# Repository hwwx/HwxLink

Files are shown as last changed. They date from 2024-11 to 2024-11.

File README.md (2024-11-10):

# HwxLink
This design aims to realize a miniaturized integrated multifunctional intelligent terminal, so it is proposed that the design is capable of accomplishing the following functions:
-	High-precision attitude sensing capability
-	Intelligent device control terminal
-	Wireless external sensor
-	Intelligent temperature detection
-	Portable DDS system
-	Simple Oscilloscope

# Repository Structure
```plaintext
HwxLink/
│
├── README.md
├── LICENSE
├── hardware/              # Hardware-related design
│   ├── pcb_layout/        # PCB design files
│   └── 3d_models/         # 3D models (if there are case designs, etc.)
│
├── software/              # Software-related code
│   ├── HwxLink_Version_3/ # Firmware code (embedded development)
│
├── words/                 # Reports and documentation
│   ├── design_report/     # Design report
│   ├── presentation/      # Design presentation
│   └── datasheets/        # Datasheets (chip or module-related documents)
│
└── images/                # Images and diagrams
    └── diagrams/          # Design diagrams, schematics.
```
# Design details
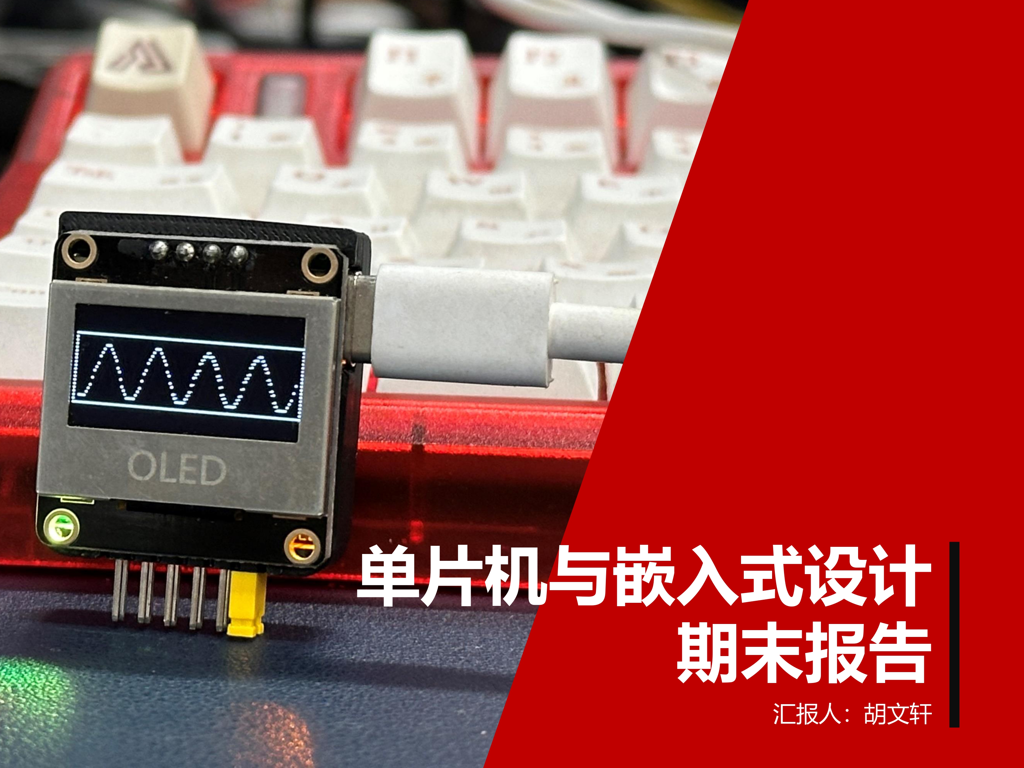
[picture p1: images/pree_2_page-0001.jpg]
Page 1

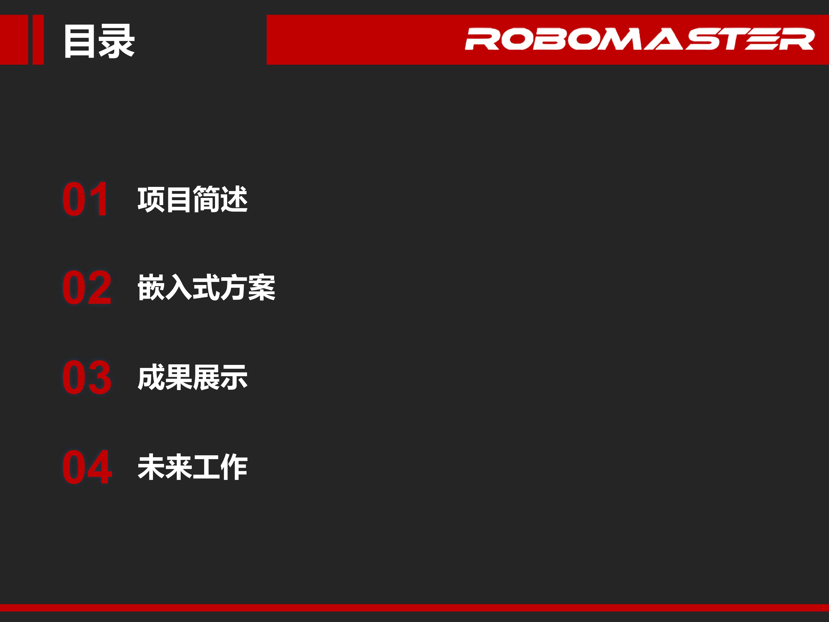
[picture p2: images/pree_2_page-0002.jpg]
Page 2

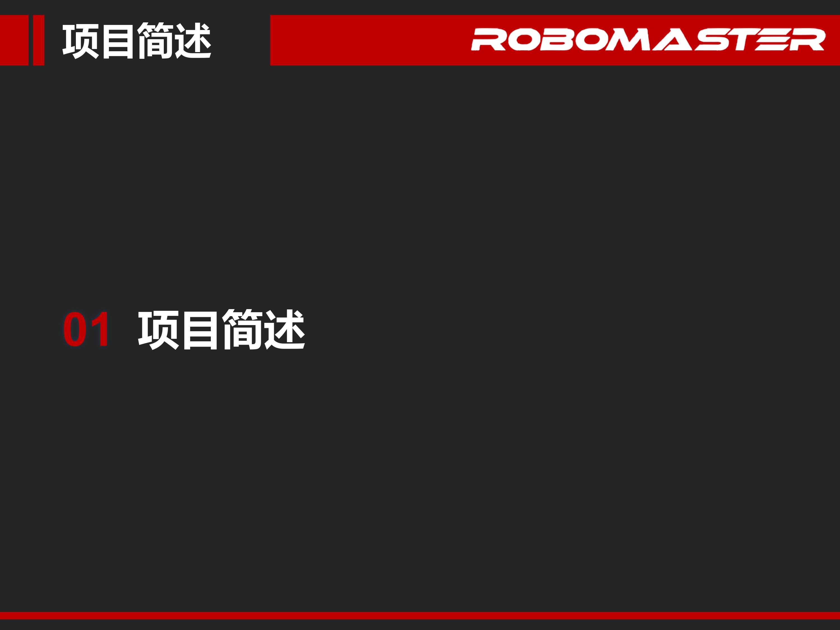
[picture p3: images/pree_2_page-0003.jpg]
Page 3

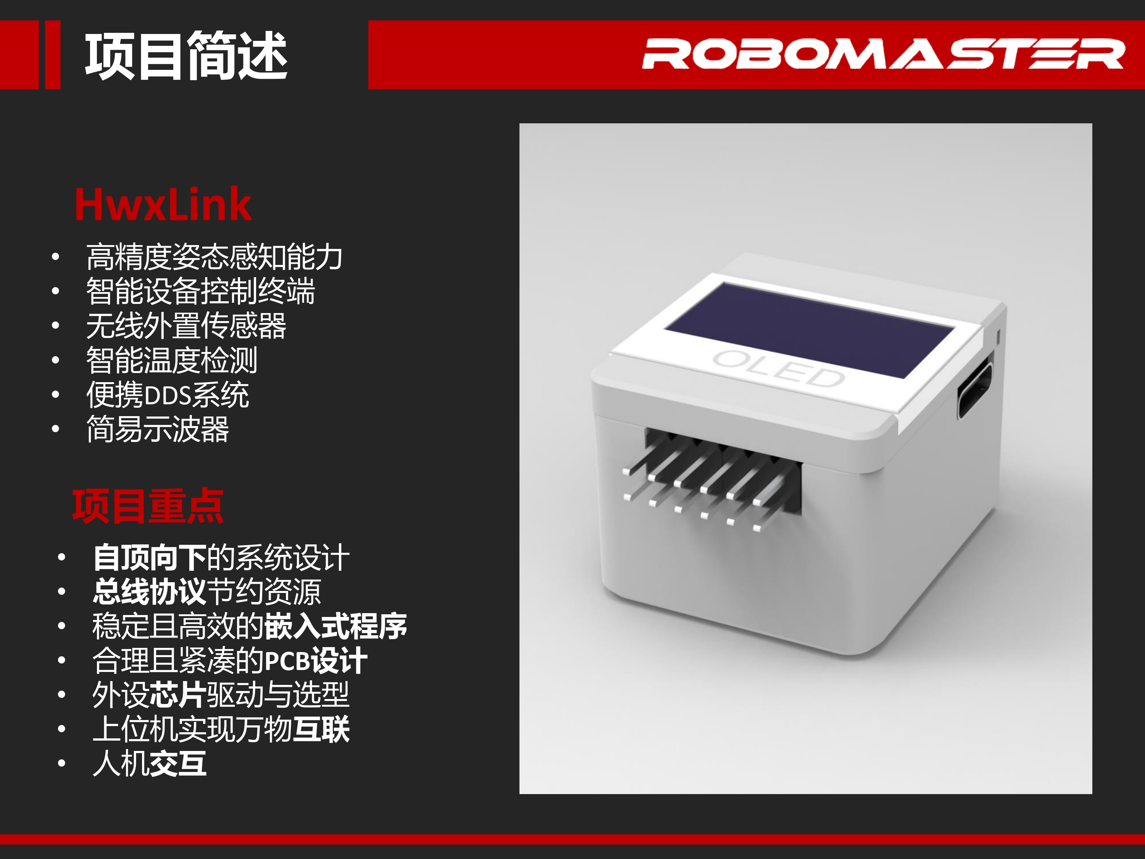
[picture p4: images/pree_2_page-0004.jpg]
Page 4

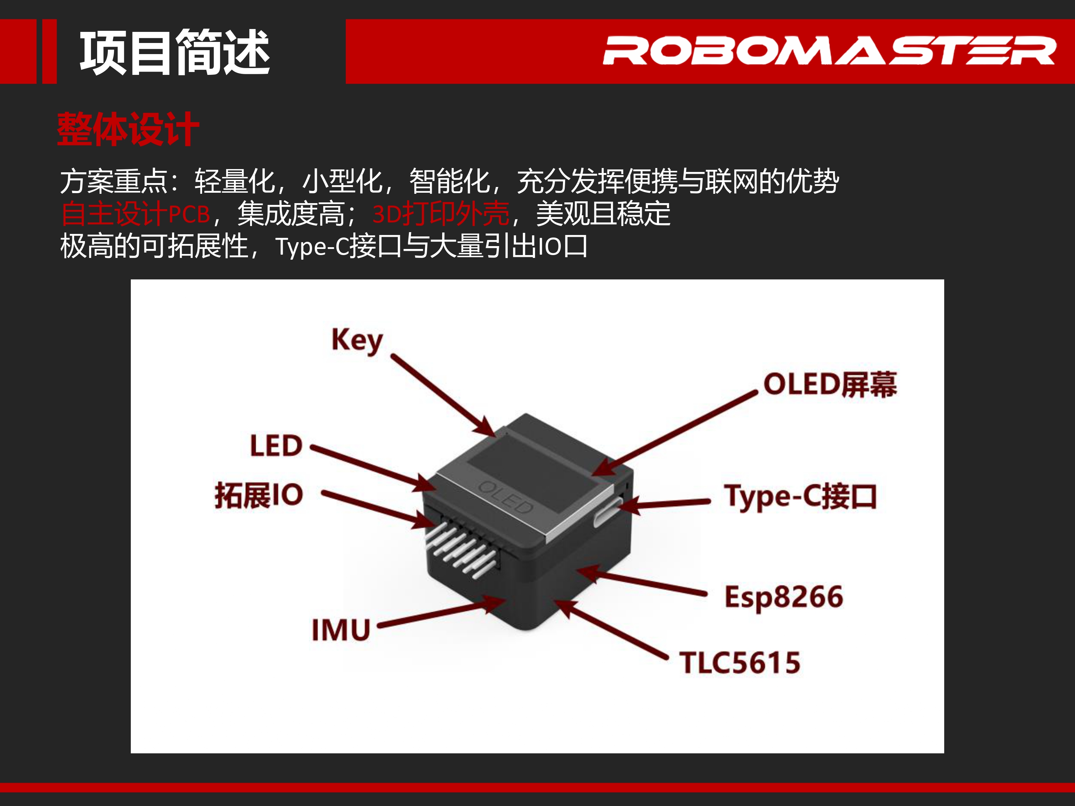
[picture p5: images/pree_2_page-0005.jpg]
Page 5

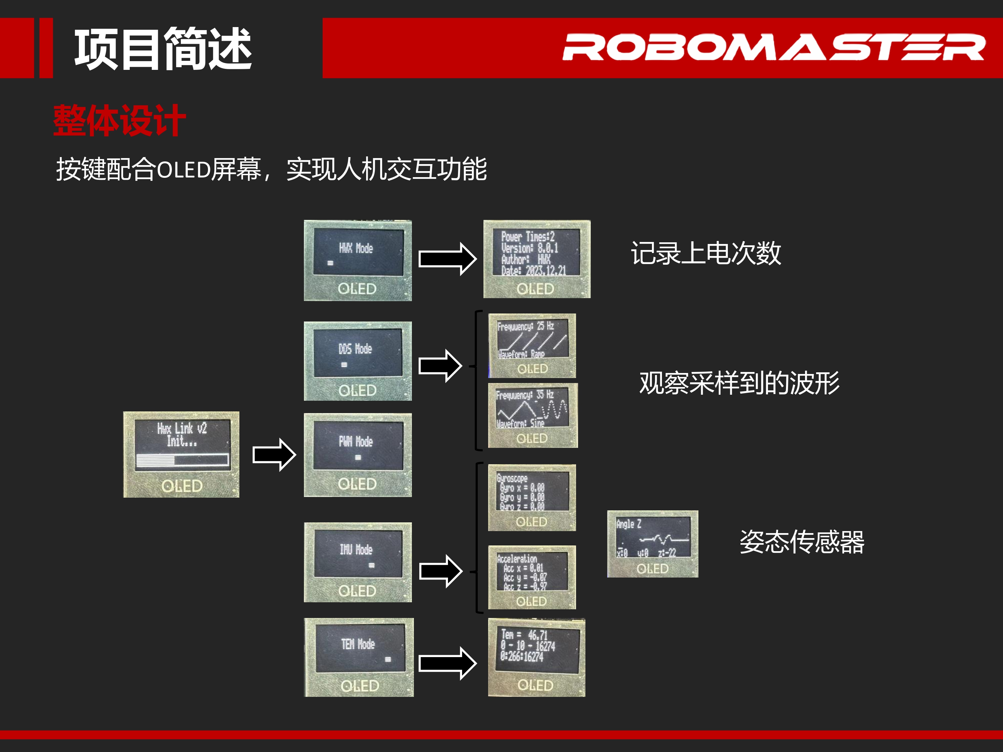
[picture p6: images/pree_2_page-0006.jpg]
Page 6

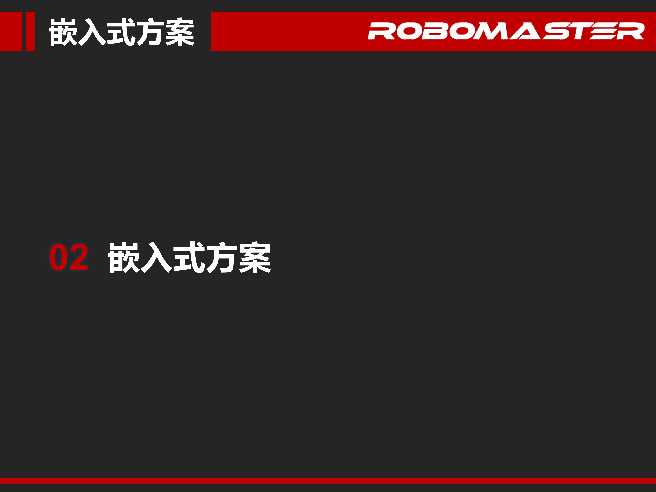
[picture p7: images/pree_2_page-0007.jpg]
Page 7

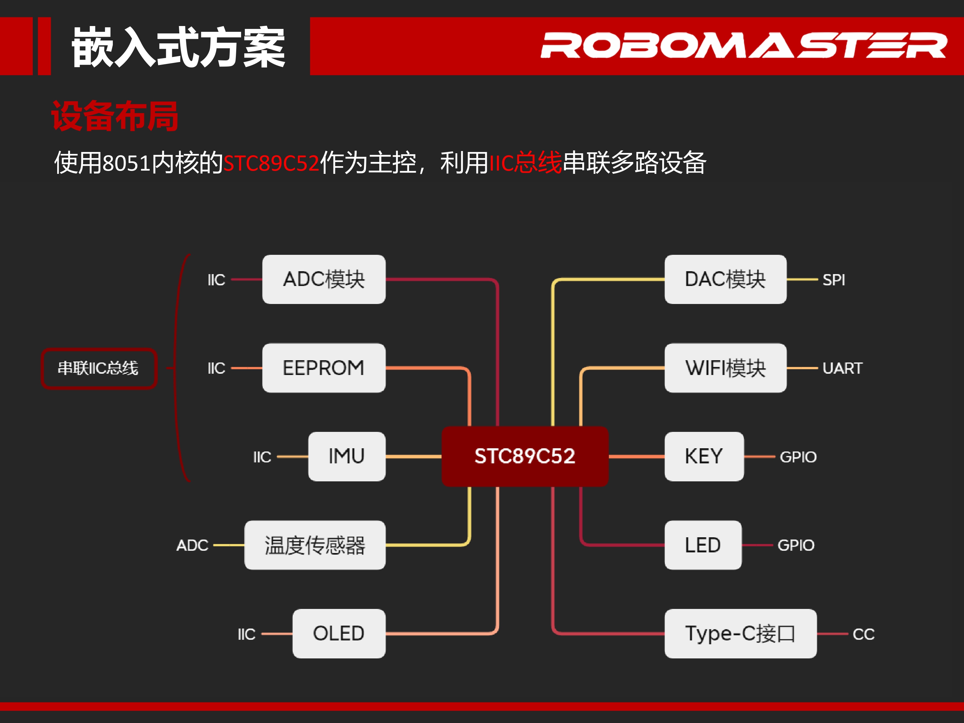
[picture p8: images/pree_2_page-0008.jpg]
Page 8

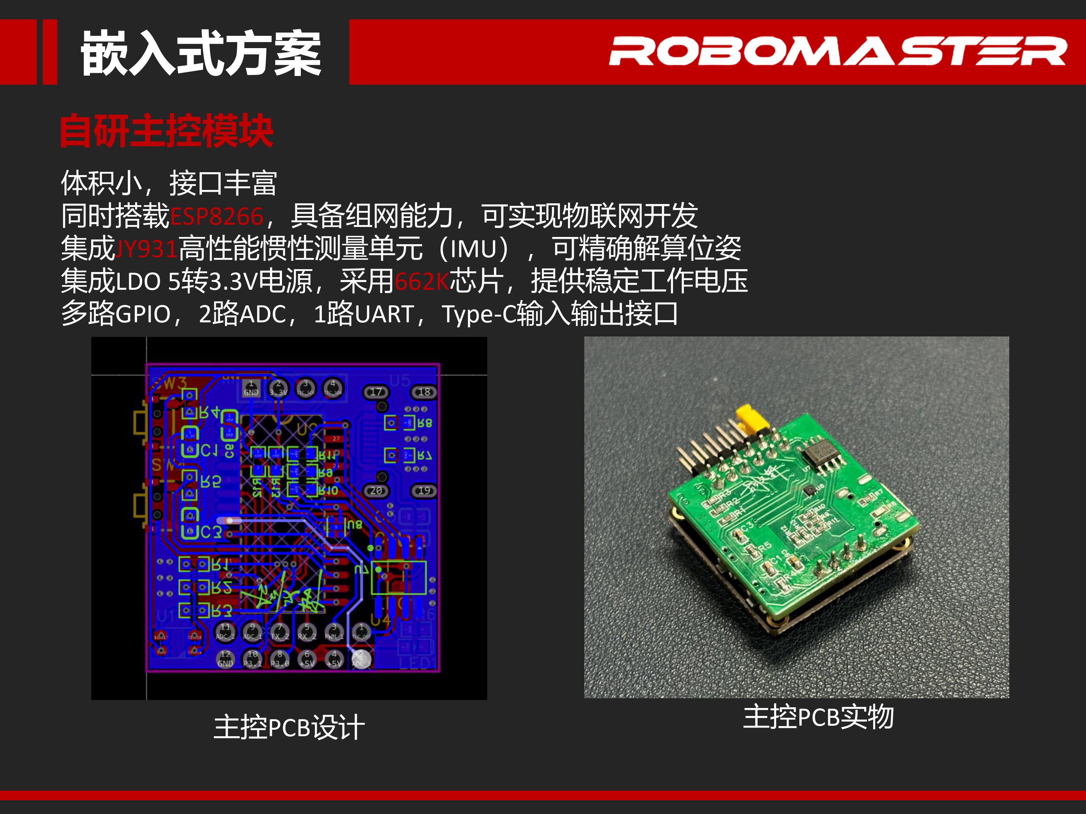
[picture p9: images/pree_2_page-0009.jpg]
Page 9

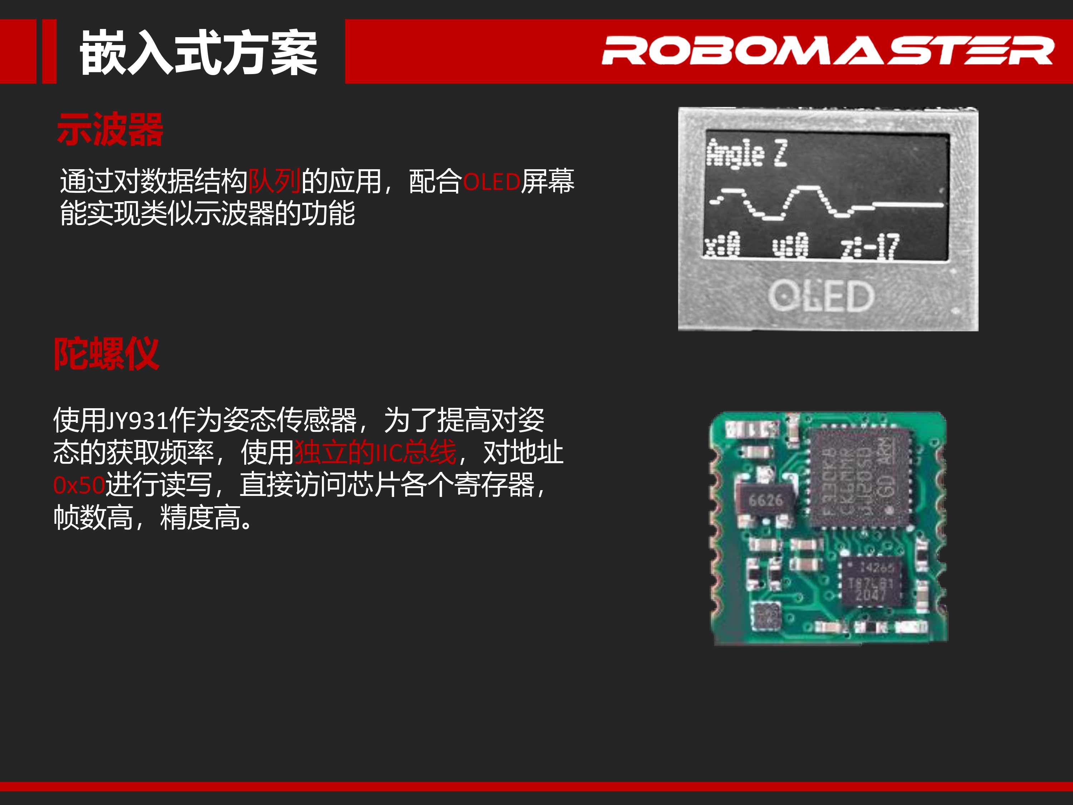
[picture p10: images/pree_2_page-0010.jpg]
Page 10

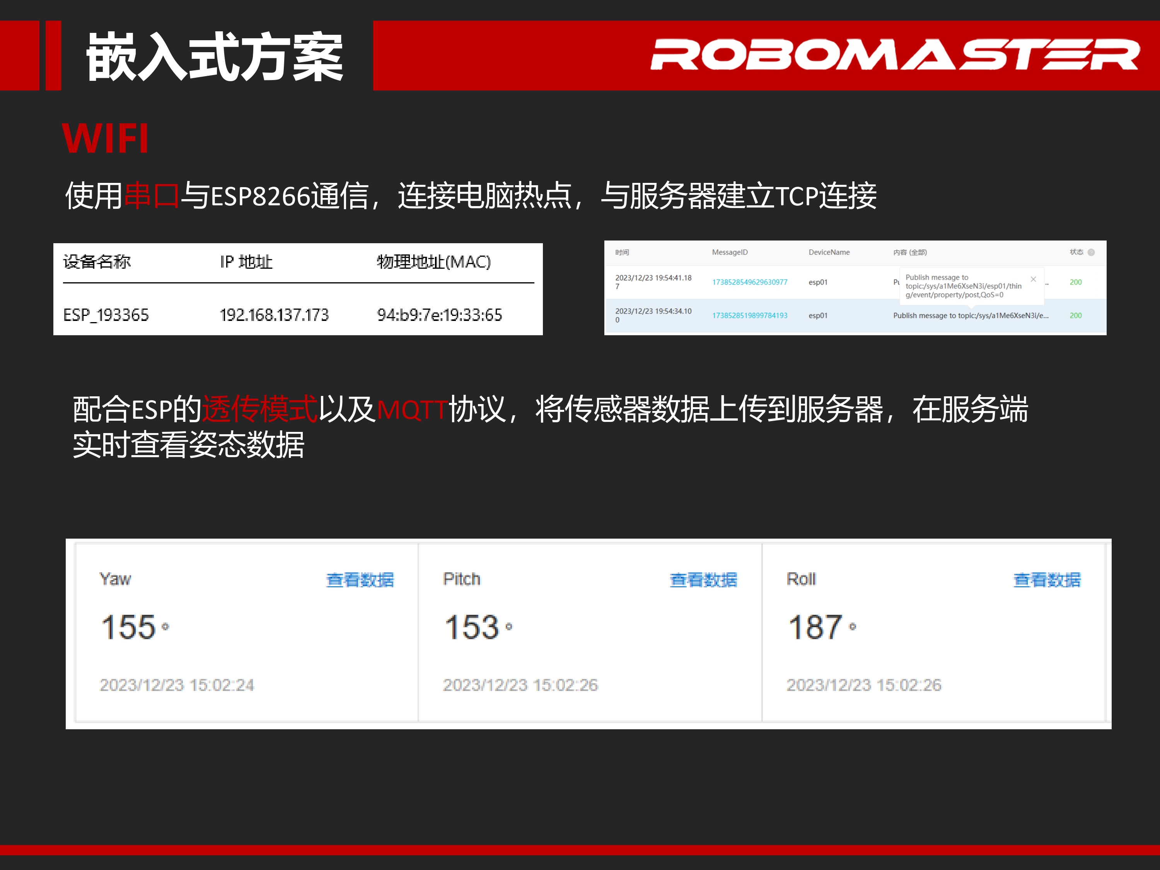
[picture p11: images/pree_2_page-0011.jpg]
Page 11

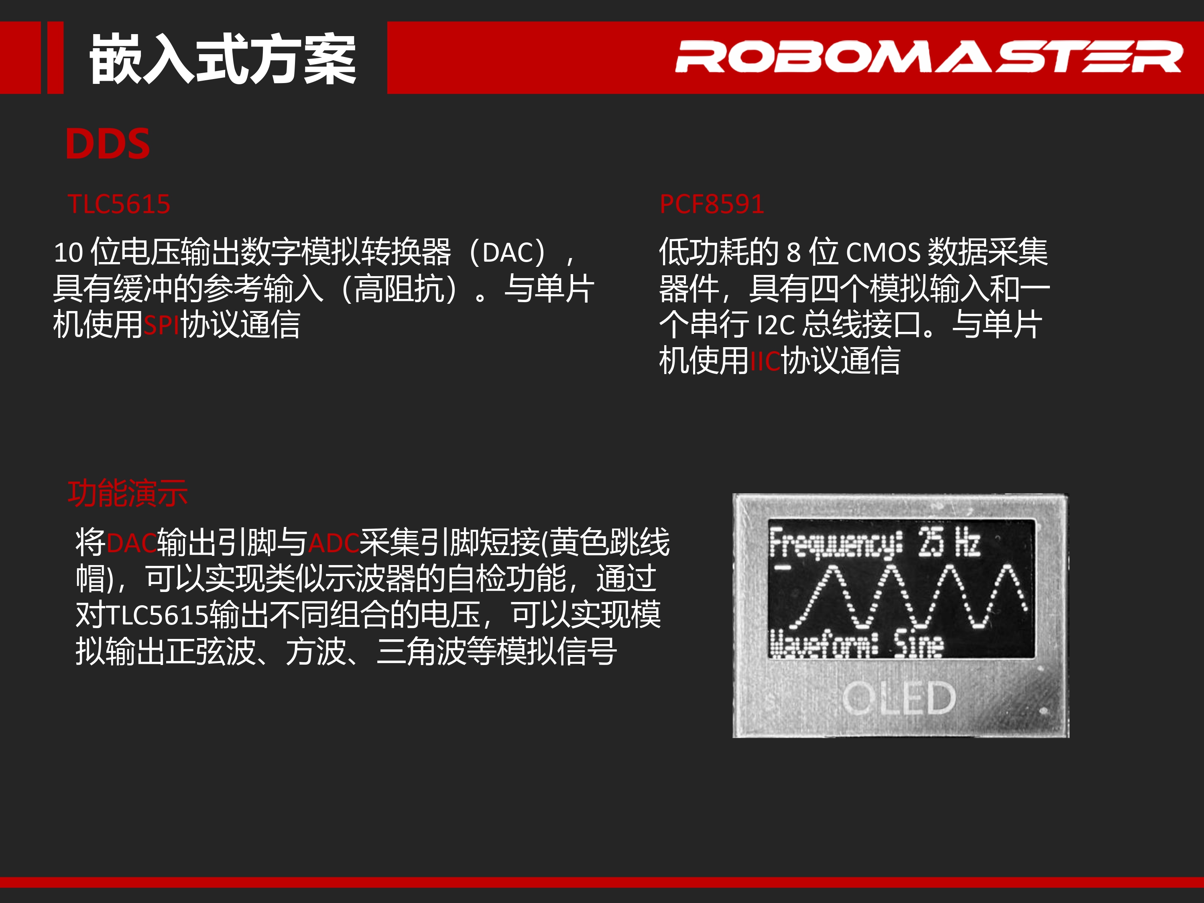
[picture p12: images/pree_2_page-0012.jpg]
Page 12

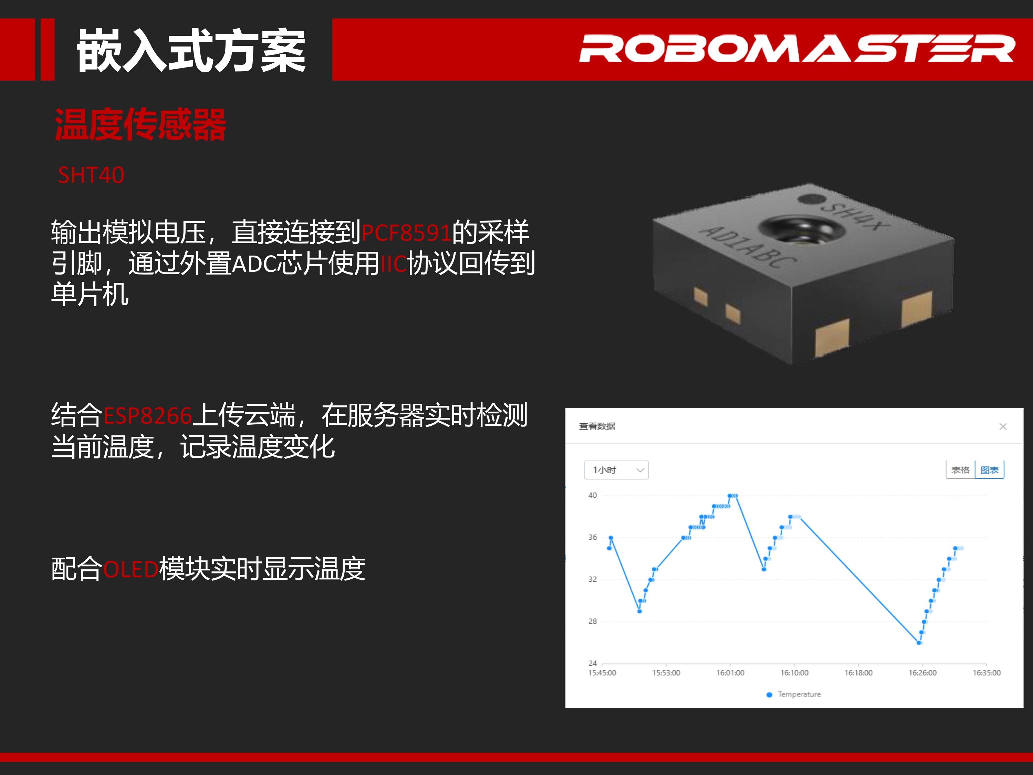
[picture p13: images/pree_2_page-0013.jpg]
Page 13

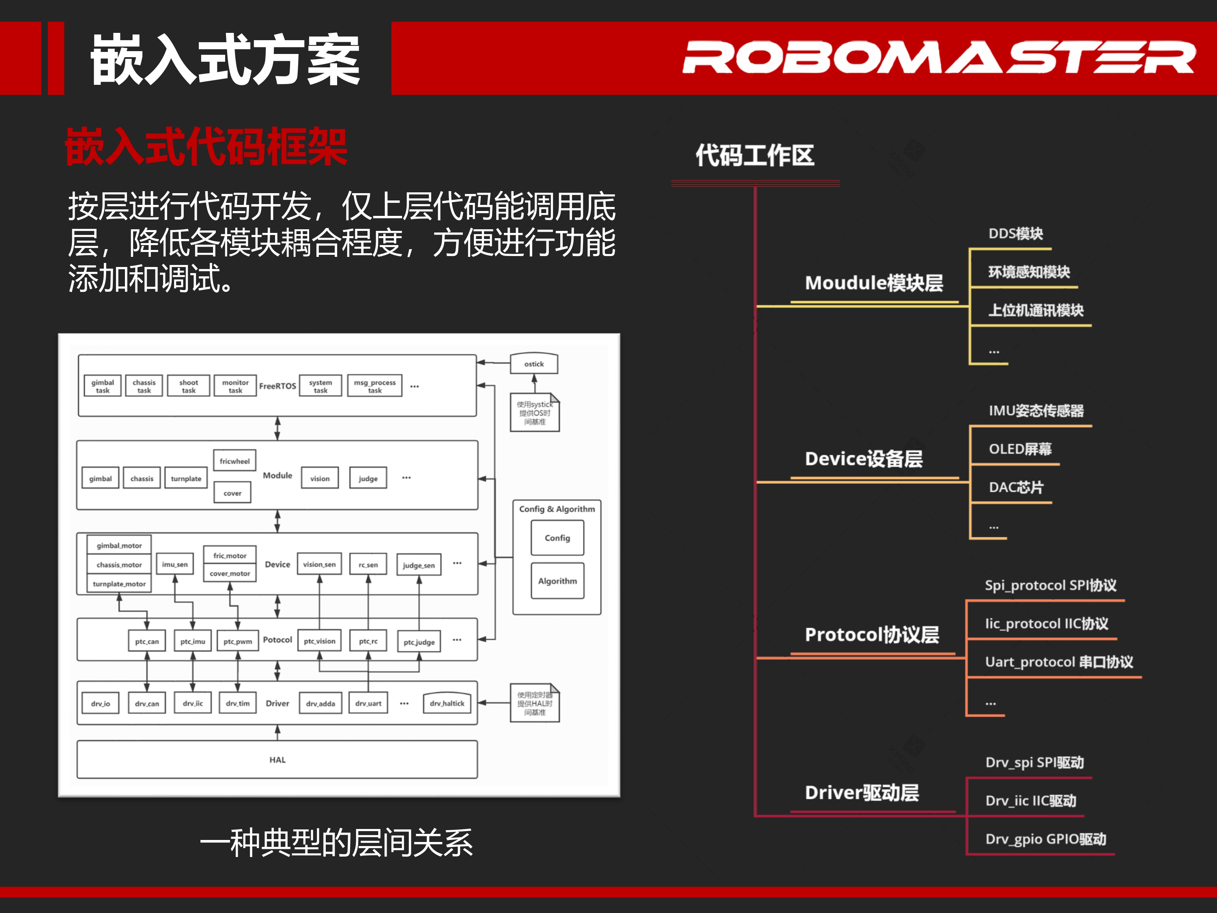
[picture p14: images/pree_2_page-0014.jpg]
Page 14

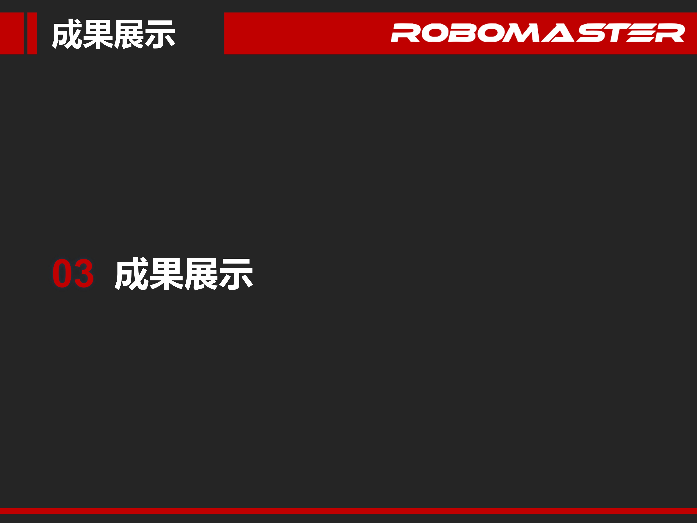
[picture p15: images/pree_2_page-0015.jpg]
Page 15

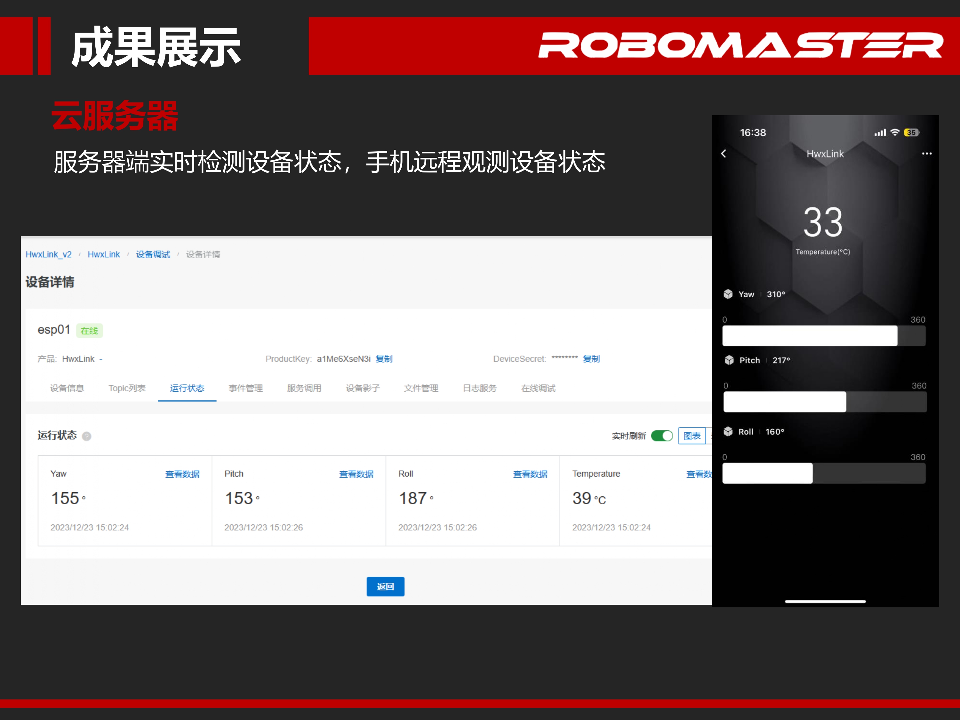
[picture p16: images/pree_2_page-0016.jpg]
Page 16

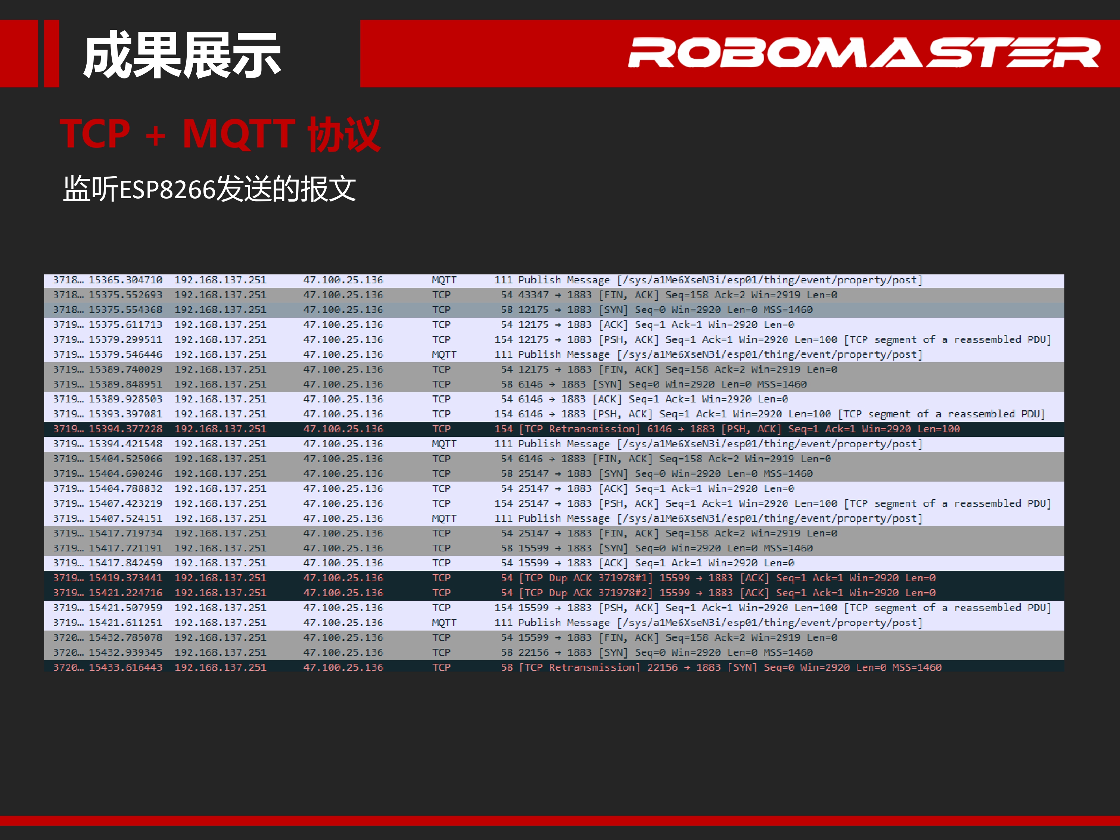
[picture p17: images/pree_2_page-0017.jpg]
Page 17

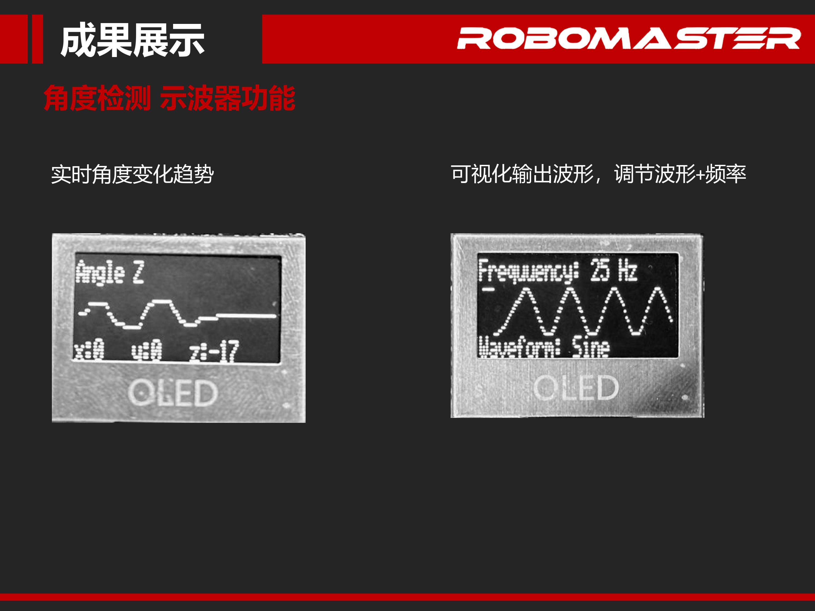
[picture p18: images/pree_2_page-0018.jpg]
Page 18

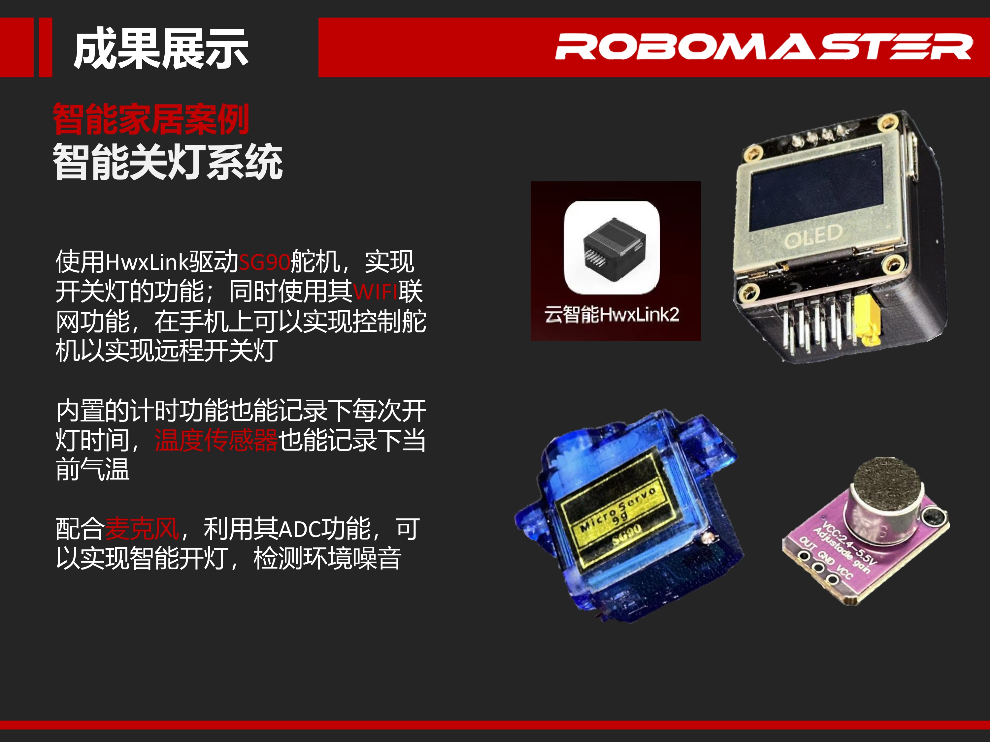
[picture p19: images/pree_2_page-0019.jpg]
Page 19

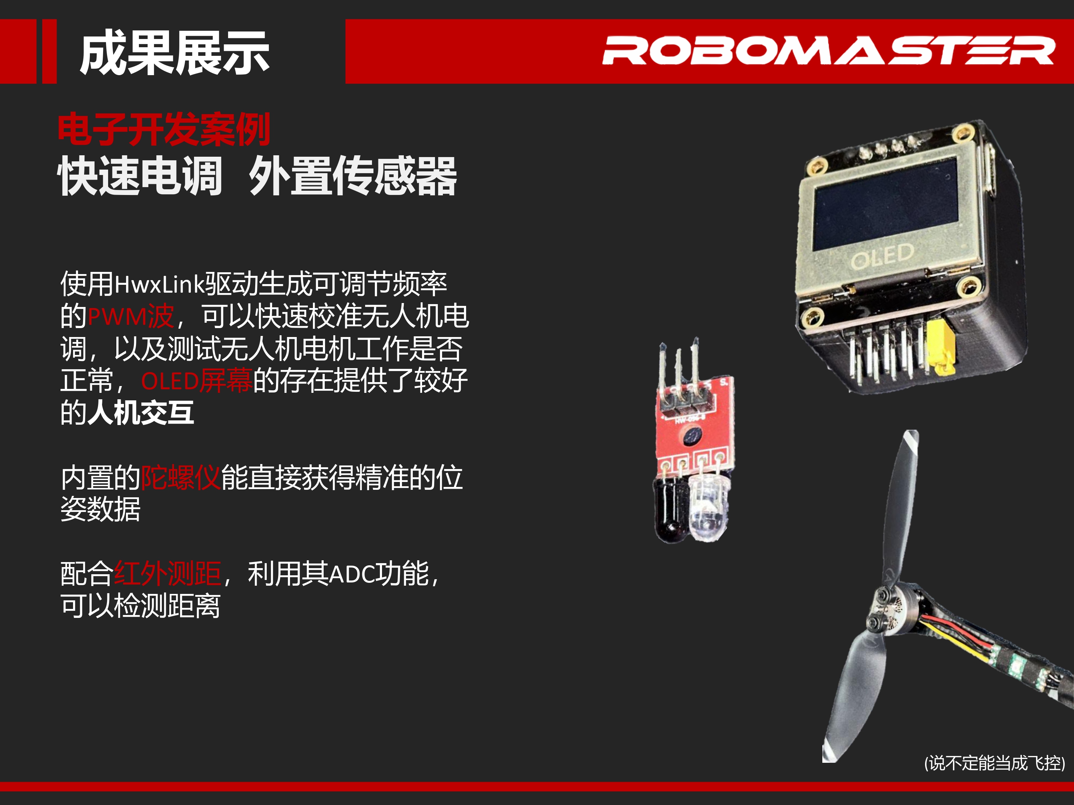
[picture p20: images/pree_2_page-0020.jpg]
Page 20

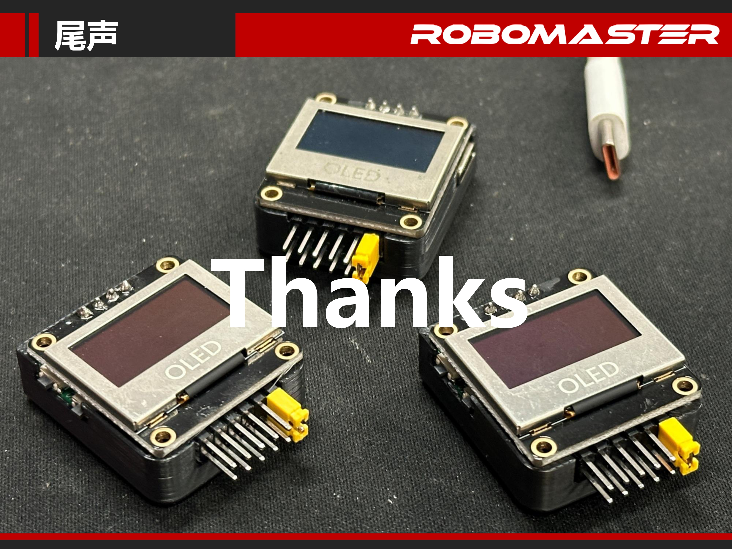
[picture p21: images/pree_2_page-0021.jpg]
Page 21


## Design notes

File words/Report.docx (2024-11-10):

# Project overview

This design aims to realize a miniaturized integrated multifunctional intelligent terminal, so it is proposed that the design is capable of accomplishing the following functions:

- High-precision attitude sensing capability
- Intelligent device control terminal
- Wireless external sensor
- Intelligent temperature detection
- Portable DDS system
- Simple Oscilloscope

In order to realize the ability of high-precision attitude perception. We need to introduce the gyroscope as the attitude sensor, at the same time, in order to allow the user to perceive the current state in real time, we also need to introduce a display module for real-time display of the current state of the device, so we introduced the keys and the display as the medium of interaction, taking into account the pursuit of a smaller volume while taking into account the characteristics of the oscilloscope, so we gave up the use of the LCD screen but the use of OLED screen As the display terminal.

In order to realize the effect of A/D input and output, we choose PCF8591 as the auxiliary chip for ADC, and use TLC5615 as the output chip for DAC, so that the 51 microcontrollers has gained the ability of analog signal input and output.

In order to realize the intelligent terminal of the Internet of Everything, we use ESP8266 as a peripheral to access the network, and at the same time, we carry out secondary development in the Internet of Things server platform of Aliyun, so as to realize the detection of various real-time states of the terminal on the cell phone side.

For the temperature sensor, we use SHT40, which can directly read the temperature in combination with ADC, and also equipped with EEPROM as the memory device.

This design follows top-down design, starting from the function, designing the circuit board, then designing the product shell, and finally debugging the code to realize the function.

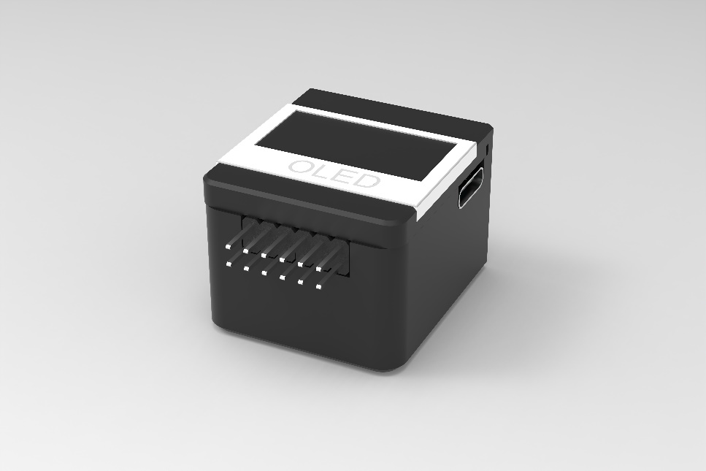
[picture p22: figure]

Figure 1 Rendering (computing)

In Figure 1, a rendering of the project is depicted using Fusion 360 modeling software. This rendering serves as a visual representation of the design or model created within the Fusion 360 environment. Key aspects to consider when describing Figure 1 include:

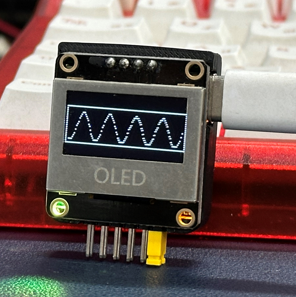
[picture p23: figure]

Figure 2 Product Picture

The final implementation and realization of the project are illustrated in Figure 2.

# Results display

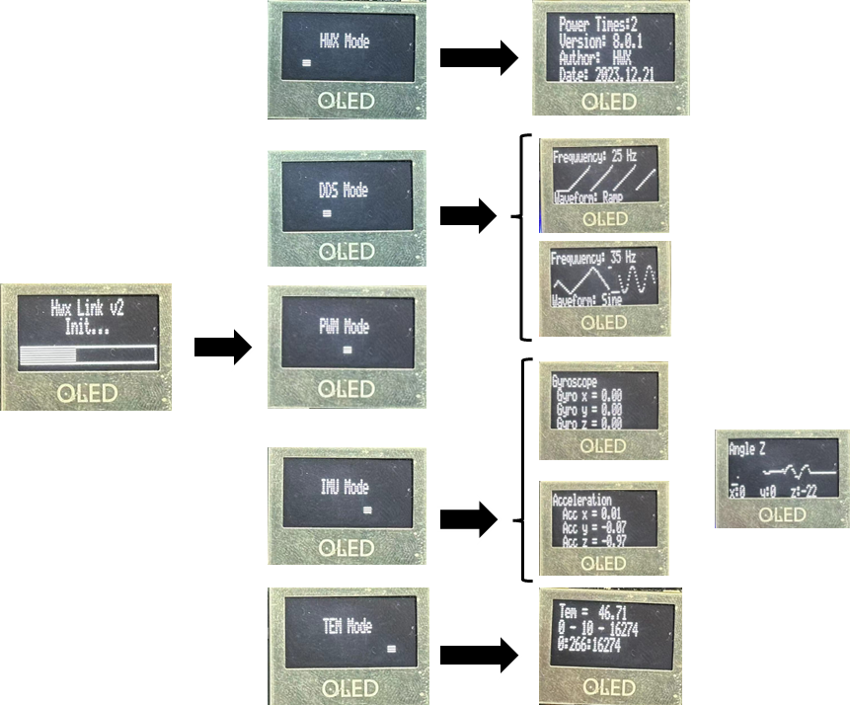
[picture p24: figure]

Figure 3 Functional diagram

The figure shows the individual modes that have been implemented, as well as the human-computer interactions

## Networking mode

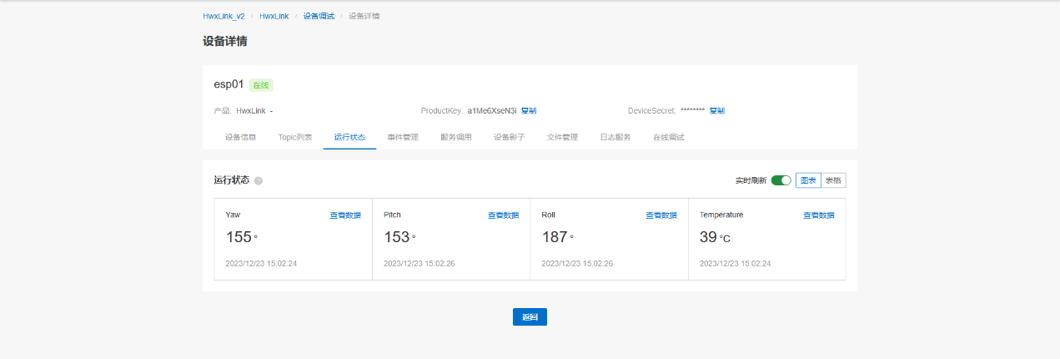
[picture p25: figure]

Figure 4 Real-time status updates

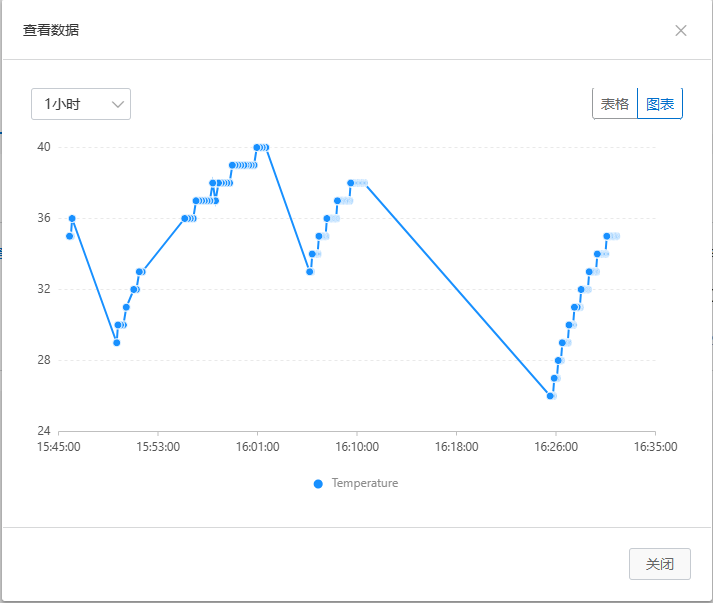
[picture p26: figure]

Figure 5 Cloud Server Detection

## The gyroscope mode

## Oscilloscope mode

## User mode

# Encounter problems

#### 1. Type-C Interface Soldering and CC Protocol:

Soldering Challenges:

- Discuss the specific challenges faced due to the small spacing between the 12 pins of the Type-C interface.
- Emphasize the difficulty in achieving precise soldering and how it impacted the overall assembly process.

CC Protocol Understanding:

- Explain the lack of understanding regarding the CC (Communication Channel) protocol in the initial version of the board.
- Highlight the consequences of not having access to the 5.1kΩ pull-down resistor on CC1 and CC2 pins, leading to the reversal of Type-C's VCC and GND pins.

#### 2. TLC5615 Output Level Issue:

Reference Source Requirement:

- Elaborate on the discovery made after reading the TLC5615 chip manual about its need for a reference source during operation.
- Discuss how the absence of the reference source resulted in incorrect output levels from the TLC5615.

#### 3. OLED Screen Frame Rate Optimization:

Initial Frame Rate Issues:

- Detail the initial challenges with the OLED screen, particularly the low frame rate impacting the interactive experience.
- Mention user experience concerns and potential usability issues.

Optimization Efforts:

- Describe the steps taken to optimize the IIC communication rate and improve the algorithm for displaying text and graphics.
- Highlight the positive impact of these optimizations on the frame rate and overall user experience.

#### 4. Serial Port Message Handling:

Function Packaging Issue:

- Explain the challenge with the serial port functionality caused by packaging the initialization into a function that adjusted the baud rate.
- Discuss the array overrun issue in Saitama and how it affected proper message handling.

Debugging with OLED Screen:

- Share how the OLED screen was utilized as a debugging device to identify and address the array overrun issue.
- Emphasize the importance of debugging tools in resolving complex issues.

#### 5. ESP8266 Connectivity and Pass-Through Mode:

Anomalous WiFi Connection:

- Discuss the abnormal ESP8266 connectivity issues and the inability to set the pass-through mode.
- Mention the reliance on the ESP official website for relevant instructions and the subsequent successful resolution.

#### 6. MQTT Protocol Understanding:

Message Reception Issue:

- Explain the problem with the server not receiving uploaded messages, attributing it to a lack of familiarity with the MQTT protocol.
- Detail the process of checking and resetting the MQTT protocol to address the communication issue.

# Integral design

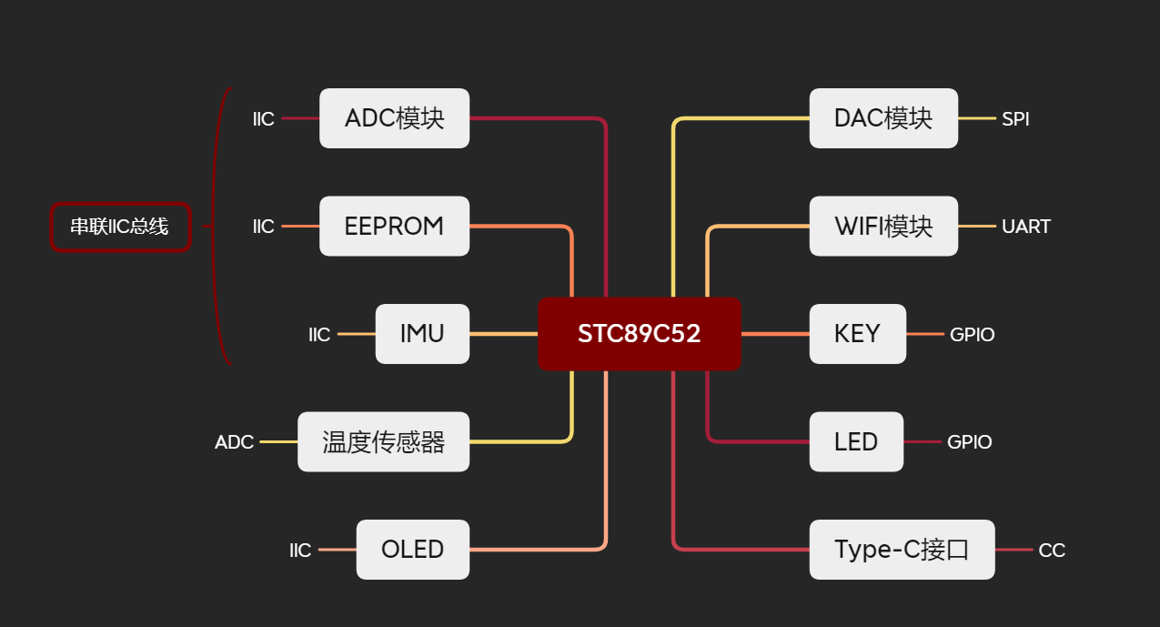
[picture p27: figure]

Figure 7 Embedded Architecture

## Peripheral device

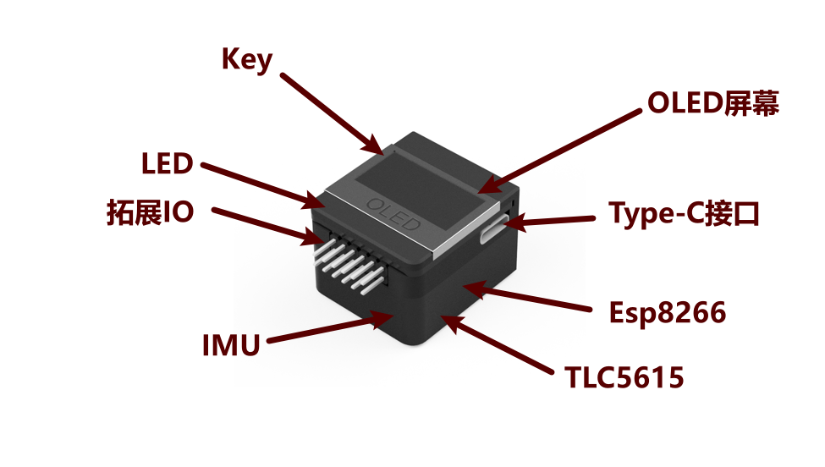
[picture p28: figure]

Figure 6 Product Composition

### SHT40

The SHT40 is a digital humidity and temperature sensor belonging to Sensirion's SHT series of products.In this product, we obtain the temperature and send it back to the MCU by means of ADC.

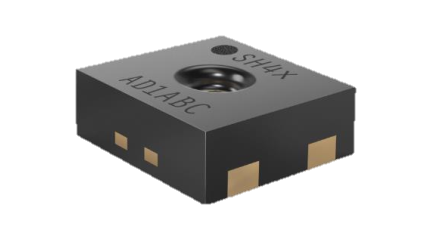
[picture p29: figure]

Functionality and Purpose:

Humidity Measurement: The SHT40 can measure the humidity level in the surrounding environment, providing highly accurate humidity data.

Temperature Measurement: In addition to humidity, the SHT40 can accurately measure the ambient temperature, providing temperature data.

Digital Sensor:

The SHT40 is a digital sensor that communicates with microcontrollers or other digital systems through a digital interface, typically I2C. This facilitates convenient data acquisition and processing.

High Accuracy and Stability:

The SHT40 is known for its high accuracy and stability, making it suitable for applications with stringent humidity and temperature requirements, such as weather measurements, industrial automation, and electronic devices.

Temperature and Humidity Calibration:

Sensors are typically calibrated during the manufacturing process to ensure accurate humidity and temperature readings. Some models also support user calibration during runtime.

Low Power Consumption:

The SHT40 generally has low power consumption during operation, making it suitable for battery-powered devices requiring extended operation.

Applications:

The SHT40 sensor finds widespread application in various scenarios that demand monitoring of environmental humidity and temperature, including but not limited to weather stations, greenhouses, industrial process monitoring, and consumer electronic devices.

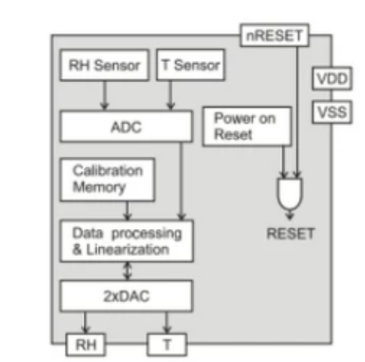
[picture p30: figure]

### TLC5615

The TLC5615 is a Digital-to-Analog Converter (DAC) produced by Texas Instruments. Here are some basic details about the TLC5615:Uses SPI to communicate with microcontroller

Features:

Digital-to-Analog Conversion:

The TLC5615 is primarily used to convert digital signals into analog voltage output. It transforms digital input data into corresponding analog voltages, suitable for driving various analog circuits and sensors.

Resolution:

The TLC5615 typically has a resolution of 12 bits, indicating that it can generate 2^12 (4096) different output voltage levels.

SPI Interface: It typically communicates using the Serial Peripheral Interface (SPI), making integration with digital systems like microcontrollers convenient.

Reference Voltage: The TLC5615 usually requires an external reference voltage to ensure the accuracy of the digital-to-analog conversion.

Applications:

Analog Signal Generation: Mainly used for generating various analog signals, such as audio waveforms, control voltages, or analog outputs from sensors.

Industrial Automation: In industrial control systems, the TLC5615 can be used to generate precise control analog voltages.

Instrumentation:

In measurement and testing equipment, the TLC5615 is employed to produce accurate analog outputs.

Operation Principle:

The TLC5615 utilizes serial input to receive digital data, which is then converted into the corresponding analog output voltage. Typically, it includes a voltage output buffer to ensure accuracy and stability in the output.

Supply Voltage:

The TLC5615 usually operates within a specific supply voltage range to ensure optimal performance.

## PCB design

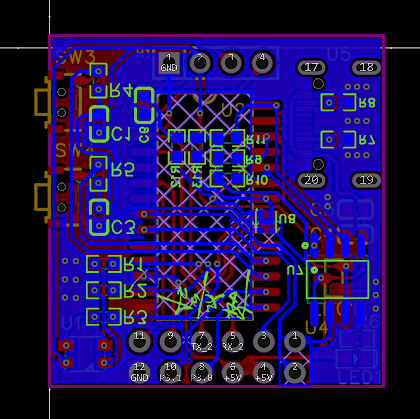
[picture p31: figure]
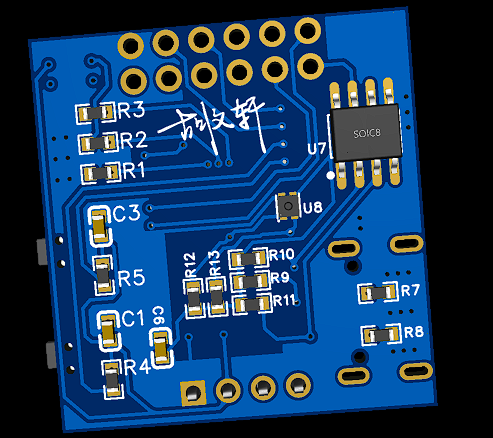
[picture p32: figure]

Figure 8 PCB

Compact Size and Rich Interface:

The design prioritizes a small form factor while maximizing interface versatility.

Despite its compact size, the PCB incorporates a rich set of interfaces to accommodate various peripherals and devices.

ESP8266 Integration for IoT Development:

The inclusion of the ESP8266 module empowers the PCB with networking capabilities, facilitating seamless IoT (Internet of Things) development.

This integration allows for wireless communication, enabling the PCB to connect to networks and exchange data in IoT applications.

High-Performance IMU (Inertial Measurement Unit):

The integration of the JY931 high-performance IMU enhances the PCB's capabilities for precise motion sensing and orientation calculations.

This feature is particularly beneficial for applications requiring accurate pose estimation and motion tracking.

Stable Power Supply with LDO 5 to 3.3V Conversion:

The design incorporates a stable power supply system featuring an LDO (Low Drop-Out) regulator for efficient voltage conversion from 5V to 3.3V.

The utilization of the SC662K chip ensures a reliable and stable operating voltage, crucial for consistent and uninterrupted performance.

Versatile GPIO, ADC, UART, and Type-C I/O:

The PCB offers multiple GPIO (General Purpose Input/Output) pins, accommodating a variety of external devices and sensors.

Two ADC (Analog-to-Digital Converter) channels enable analog signal processing, while one UART (Universal Asynchronous Receiver-Transmitter) interface facilitates serial communication.

The inclusion of a Type-C input/output interface adds modern and versatile connectivity, enhancing the PCB's compatibility with contemporary devices.

In summary, my PCB design embodies the principles of compactness, connectivity, and performance. The integration of advanced components, such as the ESP8266, JY931 IMU, and SC662K chip, enables the PCB to excel in IoT applications, motion sensing, and stable power management. The diverse set of interfaces further enhances the versatility of the design, making it well-suited for a wide range of electronic projects.

# Code implementation

Use C language to realize object-oriented ideas, encapsulate the module into a structure, to facilitate secondary development and subsequent calls.

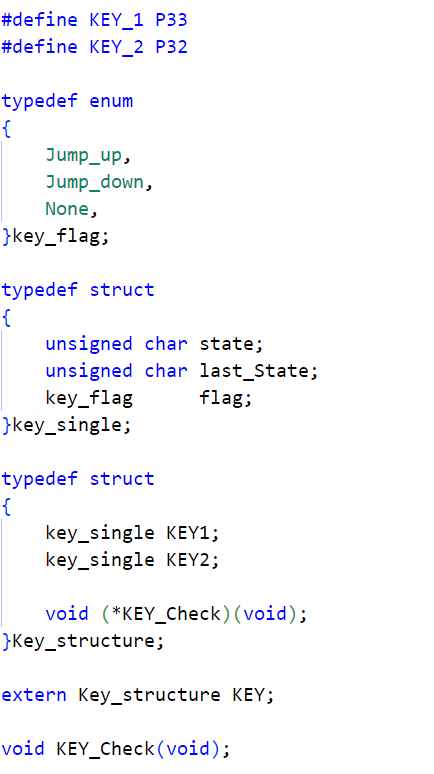
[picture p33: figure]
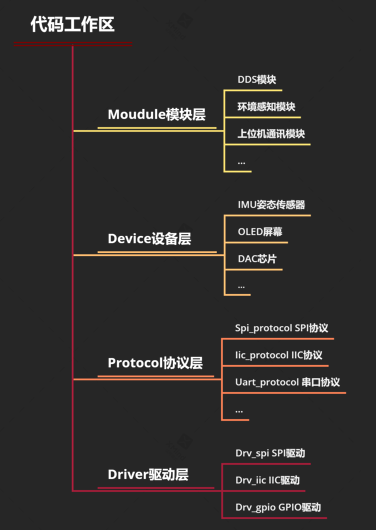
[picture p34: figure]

Figure 9 Code framework schematic

The design code implementation framework is shown in the figure above.

## Application layer

#### Main Function

int main()

{

/*初始化开始*/

GPIO_Init();

OLED_Init();

ADC_Init();

USART1_Init();

ESP8266_Init();

Queue_Init(&ADC_queue);

/*记录上电次数*/

EEPROM_read_n(0x00,&PowerOnTimes[0],1);

// _nop_();

PowerOnTimes[0]++;

// _nop_();

EEPROM_write_n(0x00,&PowerOnTimes[0],1);

OLED_bar(85);

/*初始化完成*/

OLED_Clear();

while(1)

{

switch (mode)

{

case MAIN_MODE:

if(KEY_1_cnt % CNT_MODE == MAIN_MODE)

{

unsigned char ch[22] = {0};

/*预处理*/

LED_BLUE_OFF();

LED_GREEN_OFF();

LED_RED_OFF();

/*标志位清零*/

first2bmi = 0;

first2tem = 0;

if(KEY_2_cnt % 2 == 1)

{

sprintf(ch, " Power Times:%d ", PowerOnTimes[0]);

OLED_ShowString(0, 0, (uint8_t *)ch, 20);

sprintf(ch, " Version: 8.0.1");

OLED_ShowString(0, 1, (uint8_t *)ch, 20);

sprintf(ch, " Author: HWX");

OLED_ShowString(0, 2, (uint8_t *)ch, 20);

sprintf(ch, " Date: 2023.12.21");

OLED_ShowString(0, 3, (uint8_t *)ch, 20);

}

else

{

sprintf(ch, " HWX Mode ");

OLED_drawblock(20);

OLED_ShowString(0, 1, (uint8_t *)ch, 20);

}

}

else if(KEY_1_cnt % CNT_MODE == ADC_MODE)

{

unsigned char ch[22] = {0};

sprintf(ch, " DDS Mode ");

EA = 0;

OLED_drawblock(40);

OLED_ShowString(0, 1, (uint8_t *)ch, 20);

}

else if(KEY_1_cnt % CNT_MODE == PWM_MODE)

{

unsigned char ch[22] = {0};

sprintf(ch, " PWM Mode ");

OLED_drawblock(60);

OLED_ShowString(0, 1, (uint8_t *)ch, 20);

}

else if(KEY_1_cnt % CNT_MODE == IMU_MODE)

{

unsigned char ch[22] = {0};

sprintf(ch, " IMU Mode ");

/*预处理*/

EA = 1;

first2bmi = 1;

OLED_drawblock(80);

OLED_ShowString(0, 1, (uint8_t *)ch, 20);

}

else if(KEY_1_cnt % CNT_MODE == TEM_MODE)

{

unsigned char ch[22] = {0};

sprintf(ch, " TEM Mode ");

/*预处理*/

EA = 1;

first2tem = 1;

OLED_drawblock(100);

OLED_ShowString(0, 1, (uint8_t *)ch, 20);

}

break;

case ADC_MODE:

ADC_mode_control();

MODE_Return();

break;

case PWM_MODE:

PWM_mode_control();

MODE_Return();

break;

case IMU_MODE:

BMI_mode_control();

MODE_Return();

break;

case TEM_MODE:

TEM_mode_control();

MODE_Return();

break;

default:

break;

}

}

return 0;

}

## Protocol layer

#### ESP8266 Protocol

#include "esp8266.h"

#include "JY901.h"

#include "key.h"

uint8_t AT_ok_flag = 0;

extern int16_t Pitch_,Yaw_,Roll_,Tem_;

uint32_t wifi_cnt = 0;

void ESP8266_Init(void)

{

unsigned char ch[22] = {0};

sprintf(ch, " Hwx Link v2 ");

OLED_ShowString(0, 0, (uint8_t *)ch, 16);

sprintf(ch, " Init... ");

OLED_ShowString(0, 1, (uint8_t *)ch, 16);

OLED_drawBOX();

delay_250ms();

PrintString2("ATE0\r\n"); //发送AT测试指令

while(!AT_ok_flag);

AT_ok_flag = 0;

OLED_bar(20);

PrintString2("AT+CWMODE=1\r\n");

while(!AT_ok_flag); //发送AT测试指令

AT_ok_flag = 0;

OLED_bar(40);

PrintString2("AT+CWJAP=\"HWX\",\"2021280479\"\r\n");

while(!AT_ok_flag)

{

if(wifi_cnt++ == 50000)

{

PrintString2("AT+CWJAP=\"HWX\",\"2021280479\"\r\n");

LED_BLUE_ON();

wifi_cnt = 0;

}

KEY_Check();

if(KEY.KEY1.flag == Jump_down)

{

goto herehere;

}

;

}

AT_ok_flag = 0;

OLED_bar(50);

PrintString2("AT+CIPSTART=\"TCP\",\"a1Me6XseN3i.iot-as-mqtt.cn-shanghai.aliyuncs.com\",1883\r\n");

while(!AT_ok_flag);

AT_ok_flag = 0;

OLED_bar(60);

PrintString2("AT+CIPMODE=1\r\n");

while(!AT_ok_flag);

AT_ok_flag = 0;

OLED_bar(70);

PrintString2("AT+CIPSEND\r\n");

while(!AT_ok_flag);

AT_ok_flag = 0;

Tcp_Connect();

OLED_bar(75);

}

#define WIFI_Send(x) PrintString2(x)

#define Send_Uart(x) TX2_write2buff(x)

void Tcp_Connect()

{

Send_Uart(0x10); //固定报头

Send_Uart(0x70); //剩余长度=0X10＋客户端ID长度+用户名长度+密码长度的16进制

Send_Uart(0x00); //可变报头

Send_Uart(0x04); //可变报头

WIFI_Send("MQTT"); //可变报头

Send_Uart(0x04); //可变报头

Send_Uart(0xC2); //可变报头

Send_Uart(0x00); //可变报头

Send_Uart(0x64); //可变报头

Send_Uart(0x00); //客户端ID长度00 28 即40字节

Send_Uart(0x27);

WIFI_Send("esp01|securemode=3,signmethod=hmacsha1|"); //客户端ID

Send_Uart(0x00); //用户名长度00 12 即18字节

Send_Uart(0x11);

WIFI_Send("esp01&a1Me6XseN3i"); //用户名

Send_Uart(0x00); //密码长度00 28 即40字节

Send_Uart(0x28);

WIFI_Send("a5c0c2dae092876cf199d0a1e479bb7bcae29e90"); //密码

}

u8 tabR[4] = {0}; //温度缓存单元

u8 tabP[4] = {0}; //湿度缓存单元

u8 tabY[4] = {0}; //湿度缓存单元

u8 tabT[4] = {0}; //温度缓存单元

void Up_Report_RP()

{

// Roll_ = 120;

// Pitch_ = 143;

tabR[0] = Roll_ / 100 + 0x30;

tabR[1] = Roll_ / 10 % 10 + 0x30;

tabR[2] = Roll_ % 10 + 0x30;

tabP[0] = Pitch_ / 100 + 0x30;

tabP[1] = Pitch_ / 10 % 10 + 0x30;

tabP[2] = Pitch_ % 10 + 0x30;

Send_Uart(0x30); //固定报头

Send_Uart(0x9A); //剩余长度 9A

Send_Uart(0x01);

Send_Uart(0x00); //可变报头

Send_Uart(0x30);

WIFI_Send("/sys/a1Me6XseN3i/esp01/thing/event/property/post");

WIFI_Send("{\"method\":\"thing.event.property.post\",\"id\":\"395041230\",\"params\":{\"");

WIFI_Send("Pit"); //标识符Tem

WIFI_Send("\":");

WIFI_Send(&tabP);

WIFI_Send(",\"Rol"); //标识符Hum

WIFI_Send("\":");

WIFI_Send(&tabR);

WIFI_Send("},\"version\":\"1.0.0\"}");

}

void Up_Report_YT()

{

// Yaw_ = 150;

// Tem_ = 50;

tabY[0] = Yaw_ / 100 + 0x30;

tabY[1] = Yaw_ / 10 % 10 + 0x30;

tabY[2] = Yaw_ % 10 + 0x30;

tabT[0] = Tem_ / 100 + 0x30;

tabT[1] = Tem_ / 10 % 10 + 0x30;

tabT[2] = Tem_ % 10 + 0x30;

Send_Uart(0x30); //固定报头

Send_Uart(0x9A); //剩余长度 9A

Send_Uart(0x01);

Send_Uart(0x00); //可变报头

Send_Uart(0x30);

WIFI_Send("/sys/a1Me6XseN3i/esp01/thing/event/property/post");

WIFI_Send("{\"method\":\"thing.event.property.post\",\"id\":\"395041230\",\"params\":{\"");

WIFI_Send("Yaw"); //标识符Tem

WIFI_Send("\":");

WIFI_Send(&tabY);

WIFI_Send(",\"Tem"); //标识符Hum

WIFI_Send("\":");

WIFI_Send(&tabT);

WIFI_Send("},\"version\":\"1.0.0\"}");

}

#### IMU Protocol

int16_t sReg[REGSIZE];

static uint32_t s_uiWitDataCnt = 0, s_uiProtoclo = 0, s_uiReadRegIndex = 0;

static volatile char s_cDataUpdate = 0, s_cCmd = 0xff;

static uint8_t s_ucWitDataBuff[WIT_DATA_BUFF_SIZE];

extern uint8_t YY,MM,DD,HH,MN,SS;

static uint8_t __CaliSum(uint8_t *data_, uint32_t len)

{

uint32_t i;

uint8_t ucCheck = 0;

for(i=0; i<len; i++) ucCheck += *(data_ + i);

return ucCheck;

}

void WitSerialDataIn(uint8_t ucData)

{

uint16_t usCRC16, usTemp, i, usData[4];

uint8_t ucSum;

s_ucWitDataBuff[s_uiWitDataCnt++] = ucData;

switch(s_uiProtoclo)

{

case WIT_PROTOCOL_NORMAL:

if(s_ucWitDataBuff[0] != 0x55)

{

s_uiWitDataCnt--;

memcpy(s_ucWitDataBuff, &s_ucWitDataBuff[1], s_uiWitDataCnt);

return ;

}

if(s_uiWitDataCnt >= 11)

{

ucSum = __CaliSum(s_ucWitDataBuff, 10);

if(ucSum != s_ucWitDataBuff[10])

{

s_uiWitDataCnt--;

memcpy(s_ucWitDataBuff, &s_ucWitDataBuff[1], s_uiWitDataCnt);

return ;

}

usData[0] = ((uint16_t)s_ucWitDataBuff[3] << 8) | (uint16_t)s_ucWitDataBuff[2];

usData[1] = ((uint16_t)s_ucWitDataBuff[5] << 8) | (uint16_t)s_ucWitDataBuff[4];

usData[2] = ((uint16_t)s_ucWitDataBuff[7] << 8) | (uint16_t)s_ucWitDataBuff[6];

usData[3] = ((uint16_t)s_ucWitDataBuff[9] << 8) | (uint16_t)s_ucWitDataBuff[8];

CopeWitData(s_ucWitDataBuff[1], usData, 4);

s_uiWitDataCnt = 0;

}

break;

}

if(s_uiWitDataCnt == WIT_DATA_BUFF_SIZE)s_uiWitDataCnt = 0;

}

static void SensorDataUpdata(uint32_t uiReg, uint32_t uiRegNum)

{

int i;

for(i = 0; i < uiRegNum; i++)

{

switch(uiReg)

{

// case AX:

// case AY:

case AZ:

s_cDataUpdate |= ACC_UPDATE;

break;

// case GX:

// case GY:

case GZ:

s_cDataUpdate |= GYRO_UPDATE;

break;

// case HX:

// case HY:

case HZ:

s_cDataUpdate |= MAG_UPDATE;

break;

// case Roll:

// case Pitch:

case Yaw:

s_cDataUpdate |= ANGLE_UPDATE;

break;

default:

s_cDataUpdate |= READ_UPDATE;

break;

}

uiReg++;

}

}

static void CopeWitData(uint8_t ucIndex, uint16_t *p_data, uint32_t uiLen)

{

uint32_t uiReg1 = 0, uiReg2 = 0, uiReg1Len = 0, uiReg2Len = 0;

uint16_t *p_usReg1Val = p_data;

uint16_t *p_usReg2Val = p_data+3;

uiReg1Len = 4;

switch(ucIndex)

{

case WIT_ACC: uiReg1 = AX; uiReg1Len = 3; uiReg2 = TEMP; uiReg2Len = 1; break;

case WIT_ANGLE: uiReg1 = Roll; uiReg1Len = 3; uiReg2 = VERSION; uiReg2Len = 1; break;

case WIT_TIME: YY = (uint8_t)(*p_data) >> 8;

MM = (uint8_t)(*p_data) & 0xff;

DD = (uint8_t)(*(p_data + 1)) >> 8;

HH = (uint8_t)(*(p_data + 1)) & 0xff;

MN = (uint8_t)(*(p_data + 2)) >> 8;

SS = (uint8_t)(*(p_data + 2)) & 0xff;

break;

case WIT_GYRO: uiReg1 = GX; uiLen = 3;break;

case WIT_MAGNETIC: uiReg1 = HX; uiLen = 3;break;

case WIT_DPORT: uiReg1 = D0Status; break;

case WIT_PRESS: uiReg1 = PressureL; break;

case WIT_GPS: uiReg1 = LonL; break;

case WIT_VELOCITY: uiReg1 = GPSHeight; break;

case WIT_QUATER: uiReg1 = q0; break;

case WIT_GSA: uiReg1 = SVNUM; break;

case WIT_REGVALUE: uiReg1 = s_uiReadRegIndex; break;

default:

return ;

}

if(uiLen == 3)

{

uiReg1Len = 3;

uiReg2Len = 0;

}

if(uiReg1Len)

{

memcpy(&sReg[uiReg1], p_usReg1Val, uiReg1Len<<1);

SensorDataUpdata(uiReg1, uiReg1Len);

}

if(uiReg2Len)

{

memcpy(&sReg[uiReg2], p_usReg2Val, uiReg2Len<<1);

SensorDataUpdata(uiReg2, uiReg2Len);

}

## Driver layer

#### Key Driver

void Timer2_it() interrupt TIMER2_VECTOR

{

KEY_Check();

if(KEY.KEY1.flag == Jump_down)

{

KEY_1_cnt++;

if(mode == MAIN_MODE)

{

OLED_Clear();

}

}

if(KEY.KEY2.flag == Jump_down)

{

KEY_2_cnt++;

if(mode == MAIN_MODE)

{

mode = KEY_1_cnt%CNT_MODE;

OLED_Clear();

}

}

}

#### LED Driver

sbit RGB_B = P3^6;

sbit RGB_R = P3^5;

sbit RGB_G = P3^4;

#define LED_RED_ON() (RGB_R = 0)

#define LED_RED_OFF() (RGB_R = 1)

#define LED_GREEN_ON() (RGB_G = 0)

#define LED_GREEN_OFF() (RGB_G = 1)

#define LED_BLUE_ON() (RGB_B = 0)

#define LED_BLUE_OFF() (RGB_B = 1)

#define BLACK_ON() LED_RED_OFF(); LED_GREEN_OFF();LED_BLUE_OFF()

#define RED_ON() LED_RED_ON(); LED_GREEN_OFF();LED_BLUE_OFF()

#define GREEN_ON() LED_RED_OFF(); LED_GREEN_ON();LED_BLUE_OFF()

#define BLUE_ON() LED_RED_OFF(); LED_GREEN_OFF();LED_BLUE_ON()

#define YELLOW_ON() LED_RED_ON(); LED_GREEN_ON();LED_BLUE_OFF()

#define PINK_ON() LED_RED_ON(); LED_GREEN_OFF();LED_BLUE_ON()

#define LIGHT_ON() LED_RED_OFF(); LED_GREEN_ON();LED_BLUE_ON()

#define WHITE_ON() LED_RED_ON(); LED_GREEN_ON();LED_BLUE_ON()

# Appendix

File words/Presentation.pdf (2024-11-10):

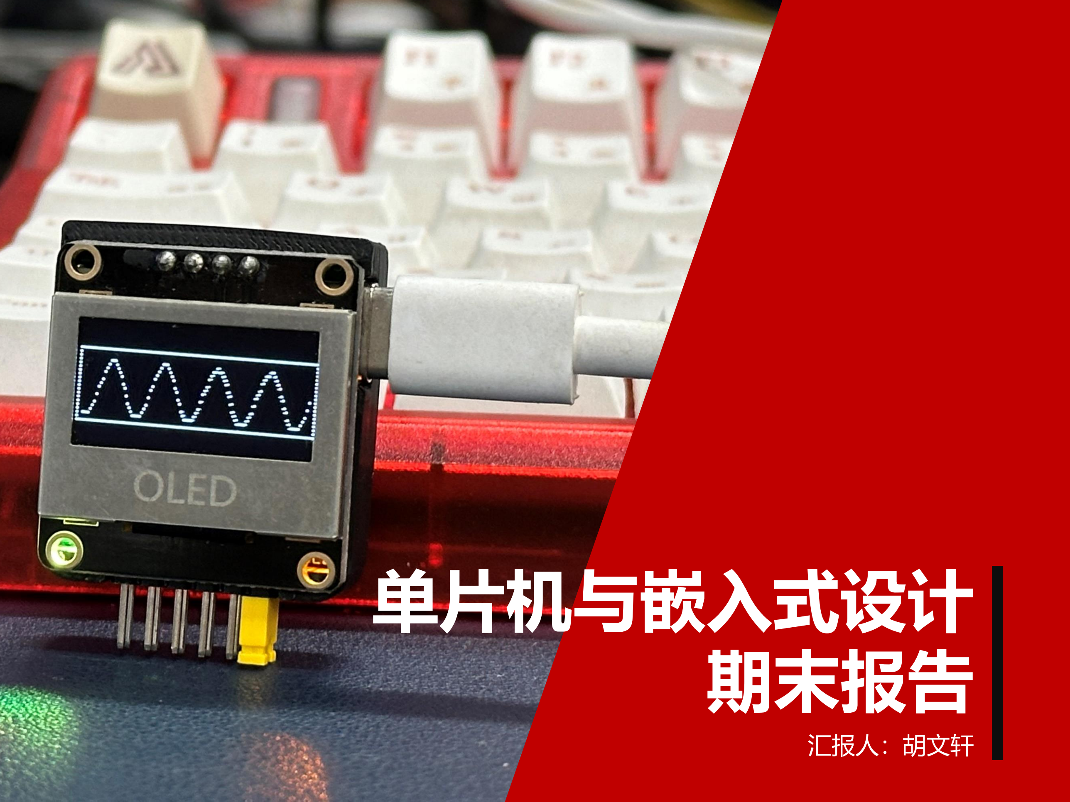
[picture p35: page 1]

# 单片机与嵌入式设计 期末报告

汇报人：胡文轩

目录

## 02 嵌入式方案

### 03 成果展示

## 04 未来工作

# 01 项目简述

# 项目简述

# 01 项目简述

# 项目简述

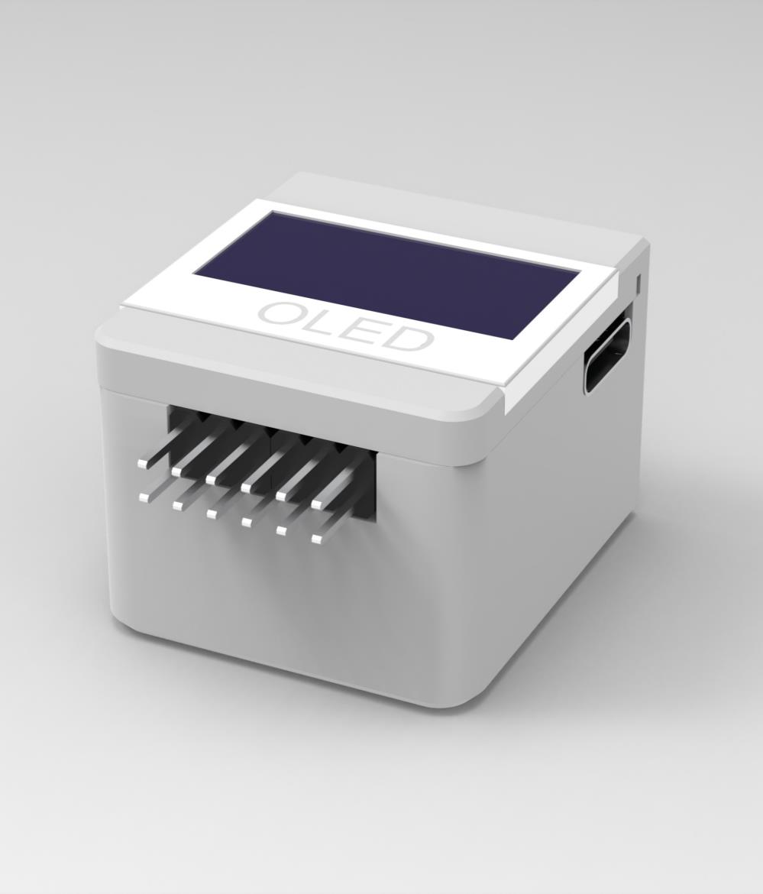
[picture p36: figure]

## HwxLink

- 高精度姿态感知能力
- 智能设备控制终端
- 无线外置传感器
- 智能温度检测
- 便携DDS系统
- 简易示波器

### 项目重点

- 自顶向下的系统设计
- 总线协议节约资源
- 稳定且高效的嵌入式程序
- 合理且紧凑的PCB设计
- 外设芯片驱动与选型
- 上位机实现万物互联
- 人机交互

# 项目简述

## 整体设计

方案重点：轻量化，小型化，智能化，充分发挥便携与联网的优势 自主设计PCB，集成度高；3D打印外壳，美观且稳定
极高的可拓展性，Type-C接口与大量引出IO口

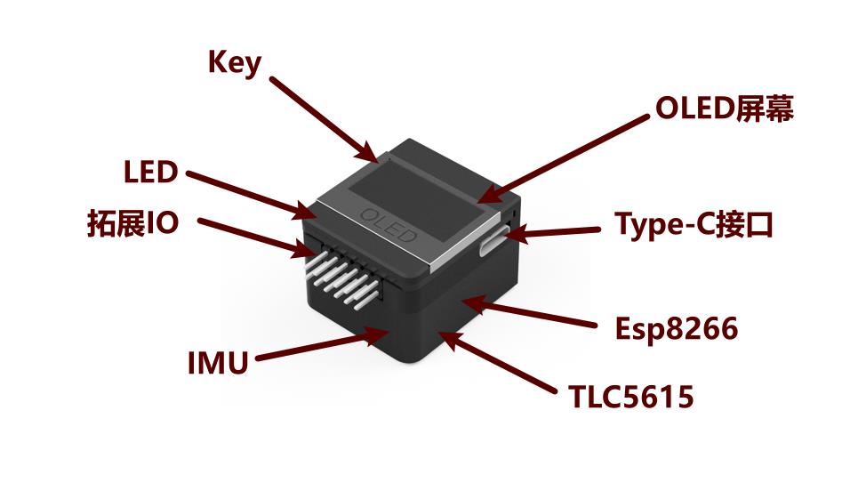
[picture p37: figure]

# 项目简述

## 整体设计

按键配合OLED屏幕，实现人机交互功能

记录上电次数

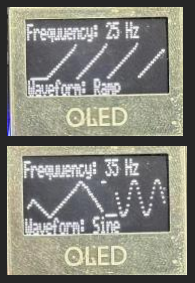
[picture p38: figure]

观察采样到的波形

姿态传感器

# 嵌入式方案

# 02 嵌入式方案

# 嵌入式方案

## 设备布局

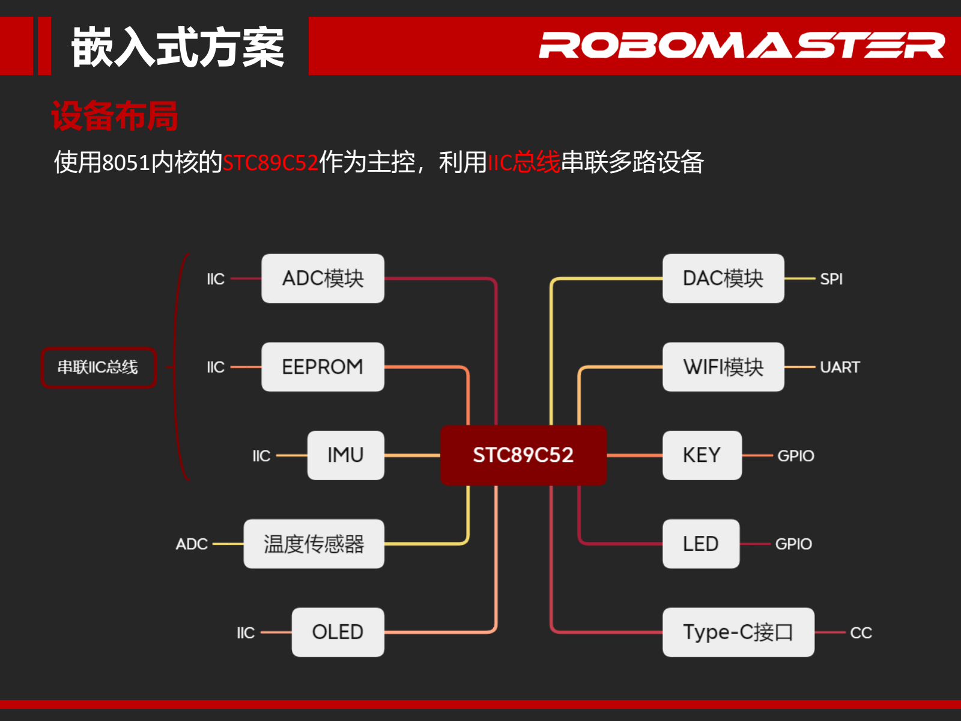
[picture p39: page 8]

使用8051内核的STC89C52作为主控，利用IIC总线串联多路设备

# 嵌入式方案

## 自研主控模块

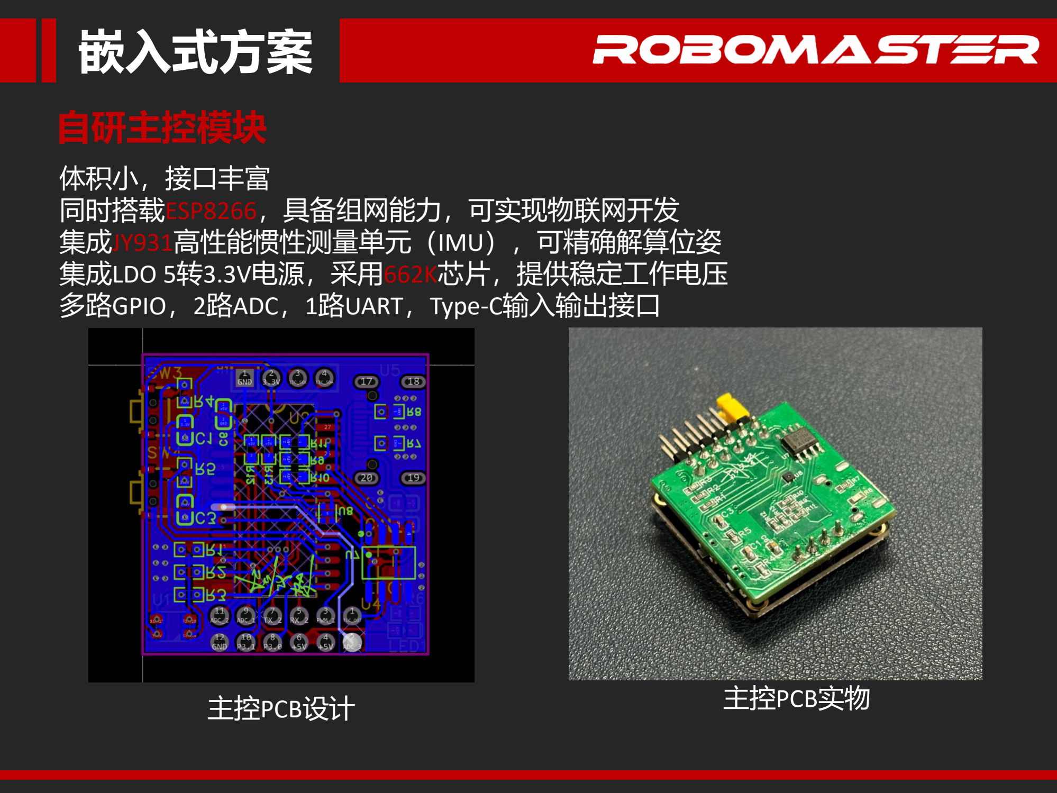
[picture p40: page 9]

体积小，接口丰富
同时搭载ESP8266，具备组网能力，可实现物联网开发 集成JY931高性能惯性测量单元（IMU），可精确解算位姿 集成LDO 5转3.3V电源，采用662K芯片，提供稳定工作电压 多路GPIO，2路ADC，1路UART，Type-C输入输出接口
主控PCB设计 | 主控PCB实物

# 嵌入式方案

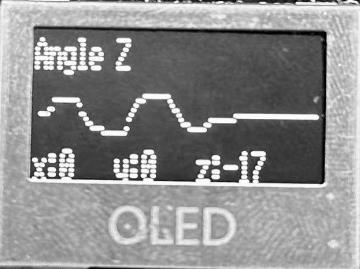
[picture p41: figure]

### 示波器

通过对数据结构队列的应用，配合OLED屏幕
能实现类似示波器的功能

## 陀螺仪

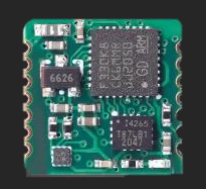
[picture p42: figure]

使用JY931作为姿态传感器，为了提高对姿
态的获取频率，使用独立的IIC总线，对地址
0x50进行读写，直接访问芯片各个寄存器，
帧数高，精度高。

# 嵌入式方案

### WIFI

使用串口与ESP8266通信，连接电脑热点，与服务器建立TCP连接

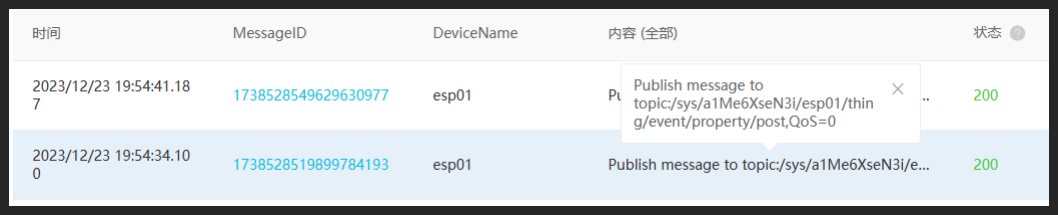
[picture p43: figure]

配合ESP的透传模式以及MQTT协议，将传感器数据上传到服务器，在服务端 实时查看姿态数据

# 嵌入式方案

### DDS

TLC5615 | PCF8591 低功耗的 8 位 CMOS 数据采集 器件，具有四个模拟输入和一

个串行 I2C 总线接口。与单片
| 机使用IIC协议通信

10 位电压输出数字模拟转换器（DAC），
具有缓冲的参考输入（高阻抗）。与单片
机使用SPI协议通信

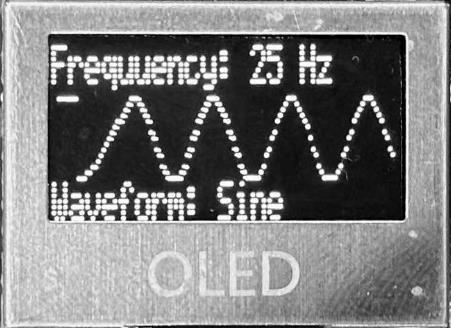
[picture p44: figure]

功能演示
将DAC输出引脚与ADC采集引脚短接(黄色跳线
帽)，可以实现类似示波器的自检功能，通过
对TLC5615输出不同组合的电压，可以实现模
拟输出正弦波、方波、三角波等模拟信号

# 嵌入式方案

## 温度传感器

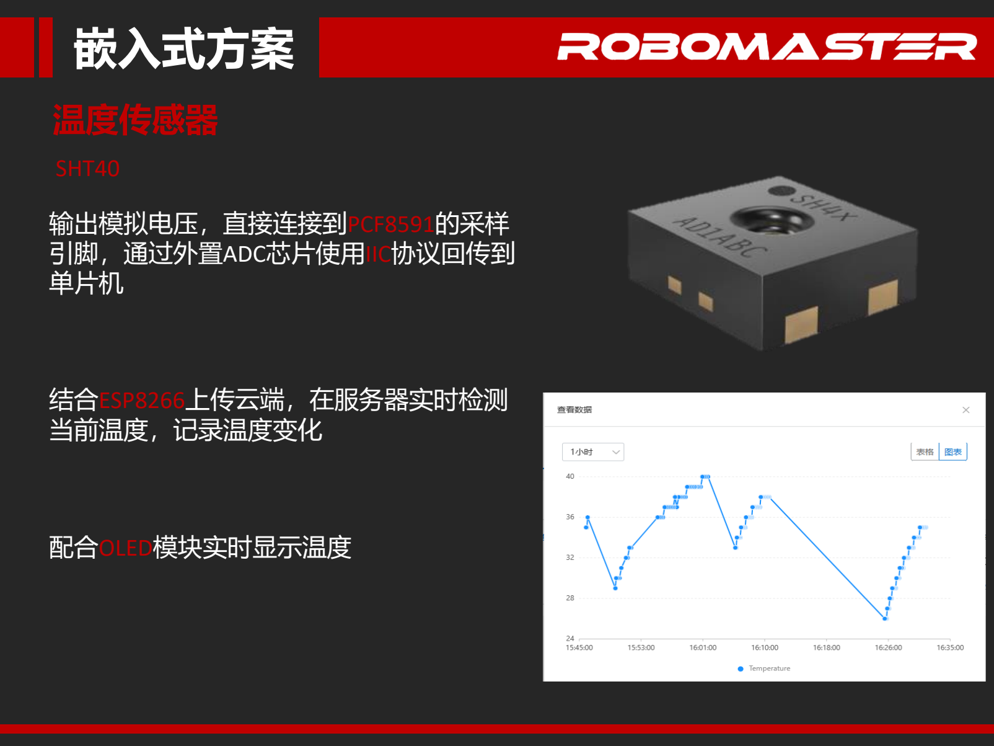
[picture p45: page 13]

SHT40

输出模拟电压，直接连接到PCF8591的采样
引脚，通过外置ADC芯片使用IIC协议回传到
单片机

结合ESP8266上传云端，在服务器实时检测
当前温度，记录温度变化

配合OLED模块实时显示温度

# 嵌入式方案

## 嵌入式代码框架


按层进行代码开发，仅上层代码能调用底
层，降低各模块耦合程度，方便进行功能
添加和调试。

一种典型的层间关系

# 成果展示

# 03 成果展示

# 成果展示

### 云服务器


服务器端实时检测设备状态，手机远程观测设备状态

# 成果展示

### TCP + MQTT 协议

监听ESP8266发送的报文


# 成果展示

## 角度检测 示波器功能

实时角度变化趋势 | 可视化输出波形，调节波形+频率

# 成果展示

## 智能家居案例

## 智能关灯系统

使用HwxLink驱动SG90舵机，实现


开关灯的功能；同时使用其WIFI联
网功能，在手机上可以实现控制舵
机以实现远程开关灯

内置的计时功能也能记录下每次开
灯时间，温度传感器也能记录下当
前气温

配合麦克风，利用其ADC功能，可
以实现智能开灯，检测环境噪音

# 成果展示

## 电子开发案例

## 快速电调 外置传感器

使用HwxLink驱动生成可调节频率
的PWM波，可以快速校准无人机电
调，以及测试无人机电机工作是否
正常，OLED屏幕的存在提供了较好
的人机交互

内置的陀螺仪能直接获得精准的位
姿数据

配合红外测距，利用其ADC功能，
可以检测距离


(说不定能当成飞控)

尾声


# Thanks
